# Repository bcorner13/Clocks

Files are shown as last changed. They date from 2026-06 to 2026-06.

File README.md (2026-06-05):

# Clocks

Parametric wall-clock product line for FreeCAD 1.1 → FDM print. One shared mounting bracket
and a parametric face template with interchangeable face SKUs.

## Product line

| File | Role | Orientation | Notes |
|---|---|---|---|
| `ClockFace-blank.FCStd` | Parametric **template** for face SKUs (disc + movement pocket) | XZ-vertical → reorient pending | base for lines/number |
| `ClockFace-lines.FCStd` | SKU: line/tick face markings (Hours ×12, HalfHour ×12) | XZ-vertical → reorient pending | |
| `ClockFace-number.FCStd` | SKU: numeric face markings | **XY-flat (target)** | clean datum-attached model |
| `ClockBracket.FCStd` | Shared wall mounting bracket | independent | |
| `Params.FCStd` | Central VarSet — all parametric variables | n/a | `<<Params>>#VarSet.Var` |

## Status (2026-06-04)

Retroactively bootstrapped to `PROJECT_BOOTSTRAP.md`. Bootstrap, central-Params migration, and
the blank/lines XY-flat reorient are **done**; the full project passes `audit_parametric.py`.
Architecture decisions and accepted tradeoffs are tracked in [`WARNINGS.md`](WARNINGS.md).

**Architecture:** central `Params.FCStd` drives all dimensions; geometry XLinks were evaluated
and **declined** (YAGNI — Params already syncs dimensions). **Remaining:** first PLA test print
(print profile TBD).

## Layout

- FCStd sources at root; `3mf/` + `stl/` tracked deliverables; `gcode/` regenerable (gitignored).
- `macros/` reviewable FreeCAD macros; `scripts/audit_parametric.py` parametric audit.
- `docs/superpowers/specs/` design specs; `docs/superpowers/plans/` execution plan.

## Standards

Inherits the workspace standards (`CAD_STANDARDS.md`, `PROJECT_BOOTSTRAP.md`,
`MCP_TOOLS_REFERENCE.md`, `tools.md`) and the global parametric rules in `~/.claude/CLAUDE.md`.
Run `python3 scripts/audit_parametric.py` before committing any geometry milestone.

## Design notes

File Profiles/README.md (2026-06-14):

# Profiles — canonical clock-face base

Home for **`ClockFace.base.3mf`** — the single source of truth that bakes print settings into
every exported face.

## What `ClockFace.base.3mf` is

A Creality Print **project** `.3mf`, saved from a *verified* 3-part face plate (the Roman plate),
containing all three things FreeCAD can't write:

- **print profile** — `Metadata/project_settings.config` (this plate: 0.12 layer, 2 walls, 15%
  infill, Textured PEI, your temps);
- **3-part structure** — dial / bezel / text as parts;
- **slot assignment + assemble** — which part prints in which CFS slot, grouped so they move together.

Because every face variant shares this structure and profile, **one base serves them all.**

## How to create / update it

In Creality Print, open a known-good 3-part plate (Roman is the reference), with the slots
assigned the way you want as defaults, then **File → Save Project As → `Profiles/ClockFace.base.3mf`**.

Re-tuned the profile (e.g. dialed in the holo plate)? Re-save the base from Creality and **every
face inherits the new settings** on its next export. Single source of truth.

This file is **tracked** in git (it's a valuable asset), unlike scratch exports in `archive/`.

## How the export uses it (the injector)

`macros/export_face_multicolor_3mf.FCMacro` will gain a `BASE_3MF` pointer to this file. On export
it:
1. copies this base,
2. swaps in the active face's three meshes (base / bezel / text, matched by order),
3. keeps `project_settings.config`, `model_settings.config`, slots, and assemble untouched,
4. writes `3mf/<DocLabel>.3mf` — opens in Creality already settings-loaded, 3-part, slot-colored.

Same trick as the 2cv001 macro ("reference a base 3MF, swap geometry, keep the rest"), just
multi-part aware. See `docs/superpowers/specs/2026-06-05-print-workflow-and-multicolor-design.md` §8.

## Status

⏳ **Base not saved yet.** The injector is built/verified against the real base once
`ClockFace.base.3mf` exists here — its exact internal structure (one-object-with-parts vs
separate-objects-with-assemble) decides the swap details, so it's developed against the actual file,
not blind.

## Also a candidate home for

Exported slicer **process profiles** (e.g. the days-tuned holo-plate profile) — back them up here or
at a workspace-level `Commercial License/Profiles/` if shared across projects. (Parked.)

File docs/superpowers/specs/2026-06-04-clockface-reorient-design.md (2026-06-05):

# ClockFace Reorient Design Spec (blank & lines → XY-flat)

**Date:** 2026-06-04
**Project:** Clocks
**Status:** Approved by Bradley — pending implementation plan
**Type:** Geometry reorient (re-attach in place; no redraw unless fallback triggers)
**Priority:** Runs after bootstrap scaffolding + Params migration (see `2026-06-04-clocks-bootstrap-design.md`)

---

## Why this exists

This spec defines the XZ→XY reorient of `ClockFace-blank` and `ClockFace-lines` to match
`ClockFace-number`. Per Bradley's final call, it honors the bootstrap spec's documented
order — **Params migration → reorient → XLink wiring** — so the reorient operates on
sketches whose dimensional constraints are already bound to `<<Params>>` expressions. The
bootstrap spec (`2026-06-04-clocks-bootstrap-design.md`) governs the scaffolding + the
Params migration that precede this reorient.

## Correction to the bootstrap spec's plane facts

Inspection of the live FCStds proved the bootstrap spec mislabeled the planes. The
corrected, verified reality:

| File | Disc lies in | Thickness along | Base `Sketch` attaches to | Markings/pocket attach to |
|---|---|---|---|---|
| `ClockFace-number` (**target**) | **XY** (flat on bed) | **Z** (0→3) | `XZ_Plane` (datum) | `XY_Plane` **datum** ✅ |
| `ClockFace-blank` (current) | XZ (standing up) | **Y** (−3→0) | `YZ_Plane` (datum) | `Revolution.Face5` **feature face** ⚠️ |
| `ClockFace-lines` (current) | XZ (standing up) | **Y** (−3→0) | `YZ_Plane` (datum) | `Pocket.Face5` **feature face** ⚠️ |

So the inconsistency is **two** problems, not one:
1. **Orientation** — blank/lines stand vertical (thickness in Y); number lies flat (thickness in Z).
2. **Coupling/DAG debt** — blank/lines anchor downstream sketches to *feature faces*; number anchors to the `XY_Plane` *datum*. The global rules flag feature-face attachment as a DAG-cycle red flag.

`ClockFace-number` already embodies the clean target on both counts. The goal of this work
is to make blank and lines match it.

## Verified current recipes

**number (target):** base `Sketch` on `XZ_Plane`; `Revolution` axis ≈ (0,0,−1) → spins
profile around **Z**, disc flat in XY (Z 0→3); `Sketch001` (movement pocket) on `XY_Plane`
datum.

**blank (current):** base `Sketch` on `YZ_Plane`; `Revolution` axis = (0,1,0) → spins
around **Y**, disc in XZ (Y −3→0); `Sketch001` on `Revolution.Face5`; `Pocket` UpToFirst.

**lines (current):** identical base to blank, plus `Sketch002` "Hours" (4 line segments,
11 constraints) → `Pad` 1.0mm → `PolarPattern` ×12 around sketch N_Axis; and `Sketch004`
"HalfHour" (5 line segments, 14 constraints) → `Pad001` 0.5mm → `PolarPattern001` ×12.
Both marking sketches anchor to `Pocket.Face5` (feature face ⚠️).

## Approach — re-attach in place (decided)

Chosen over (a) Body.Placement rotation and (b) re-attach base sketch only. Rationale:
matches number's clean datum structure, fixes orientation AND DAG debt in one pass, and
preserves all constrained geometry. The reorient is **independent of the constraint
values** — re-attaching a sketch to a different datum does not touch its dimensional
constraints. Since Params migration runs first, those constraints are already
`<<Params>>#VarSet.Var` expressions when the reorient happens, and re-attachment preserves
them unchanged.

### ClockFace-blank (macro `macros/reorient_blank_to_xy.FCMacro`)
1. Snapshot to `ClockFace-blank.Session-20260604.FCStd` first (session-hygiene rule).
2. Re-attach base `Sketch`: `YZ_Plane` → `XZ_Plane`, matching number's MapMode/placement,
   so the revolve axis becomes Z and the disc lands flat in XY.
3. Retarget `Sketch001` (movement pocket): `Revolution.Face5` → `XY_Plane` datum, as number does.
4. Recompute. Verify disc flat in XY (bbox dz ≈ 3, disc in XY), pocket on the correct face.
   Flip `Revolution.Reversed` / `Pocket.Reversed` if the solid builds on the wrong side.
5. Screenshot for Bradley's review. **No save until approved.**

### ClockFace-lines (macro `macros/reorient_lines_to_xy.FCMacro`)
Steps 1–3 as blank, then:
6. Retarget `Sketch002` (Hours) and `Sketch004` (HalfHour): `Pocket.Face5` → `XY_Plane`
   datum (or a thin offset datum at the face surface), preserving line geometry + polar patterns.
7. Recompute full tree (Pocket → Pad → PolarPattern → Pad001 → PolarPattern001).
8. Verify markings sit on the visible face, centered and radial; screenshot for review.

### Fallback for markings (decided: recreate)
Marking sketches were authored in the `Pocket.Face5` local frame; their 2D coordinates may
not land correctly on the `XY_Plane` datum. If a re-attached marking sketch mis-places, the
fallback is to **recreate that sketch** on the datum to match the original geometry (same
segment lengths, radial positions, constraints), verified visually. Bradley chose recreate
over pause-and-show. Because Params migration runs first, a recreated sketch binds its
dimensional constraints **directly to `<<Params>>` expressions** — no literal-coordinate
debt is introduced (this supersedes the earlier R4 concern).

## Constraints / rules honored

- All edits via reviewable macros under `macros/`; no direct FCStd XML surgery.
- Sketches end up on **datum/principal planes only** — never feature faces (global rule #3).
- **No raw coordinate edits** to fix geometry; reorientation is via attachment + revolve axis,
  not by editing StartX/EndY etc. (global rules #1/#2). Recreate-fallback redraws against the
  same dimensional intent, to be Params-migrated later.
- Dimensional constraints are **left as-is** (still literals) — Params migration is a separate,
  later pass and is explicitly out of scope here.

## Out of scope (handled elsewhere, not in this spec)

- Params migration (literals → `<<Params>>#VarSet.Var`) — runs **before** this reorient, per
  the bootstrap spec. Not redefined here.
- XLink wiring (lines/number → blank) — runs after this reorient.
- Any change to `ClockBracket.FCStd`.
- Re-export of STL/3MF — **decided: leave for later** (reorient FCStd source only this session;
  regenerate exports after Bradley reviews the reoriented models).

## Sequence (honors bootstrap spec ordering)

1. Retroactive bootstrap scaffolding per `2026-06-04-clocks-bootstrap-design.md` (creates the
   empty `Params.FCStd`, CLAUDE.md, audit, git, etc.).
2. Params migration: populate `Params.FCStd` and rewrite literal dimensional constraints in
   blank/lines/number/bracket as `<<Params>>#VarSet.Var` expressions.
3. Reorient blank → verify/screenshot → Bradley approves → save.
4. Reorient lines → verify/screenshot → Bradley approves → save.
5. (Later) XLink wiring.

The stub `macros/reorient_blank_lines_to_xy.FCMacro` named in the bootstrap spec is superseded
by the two real macros above (`reorient_blank_to_xy.FCMacro`, `reorient_lines_to_xy.FCMacro`);
note this in the bootstrap scaffolding.

## Acceptance criteria

- [ ] `ClockFace-blank`: base `Sketch` on `XZ_Plane`; `Sketch001` on `XY_Plane` datum;
      bbox thickness along Z (dz ≈ 3), disc in XY; recompute clean (no DAG errors).
- [ ] `ClockFace-lines`: same as blank, plus `Sketch002`/`Sketch004` on a datum (not
      `Pocket.Face5`); polar patterns intact (×12 each); markings centered/radial on the face.
- [ ] No sketch in either file attaches to a feature face after the reorient.
- [ ] Dimensional constraints remain bound to `<<Params>>` expressions through the reorient
      (re-attached sketches keep their expressions; any recreated sketch binds to Params).
- [ ] A pre-edit `*.Session-20260604.FCStd` snapshot exists for each file.
- [ ] Both files saved only after Bradley approves the screenshots.
- [ ] STL/3MF not regenerated (deferred).

## Risks

- **R1 — Marking sketches mis-place on re-attach.** Mitigated by the recreate fallback.
- **R2 — Revolve builds on the wrong side after axis change.** Mitigated by checking bbox
  Z-range and flipping `Reversed`.
- **R3 — `FaceN` topological-naming breakage cascades during re-attach.** Expected; the whole
  point is to move *off* those faces onto datums. Recompute after each step and verify before
  proceeding to the next sketch.
- **R4 — Recreate-fallback geometry drift.** Because Params migration runs first, a recreated
  sketch binds directly to `<<Params>>` expressions (no literal debt). Residual risk is only
  visual placement drift, mitigated by screenshot verification before save.

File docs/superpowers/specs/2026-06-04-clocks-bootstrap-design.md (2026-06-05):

# Clocks Project — Bootstrap Design Spec

**Date:** 2026-06-04
**Project:** Clocks
**Status:** Approved — pending implementation plan
**Type:** Retroactive project bootstrap (scaffolding-only; no geometry edits)

---

## Overview

The `Clocks/` folder under `~/Documents/3dPrinting/Commercial License/` already contains five in-progress FCStd files and exported `.stl`/`.3mf` outputs but has none of the structure required by `PROJECT_BOOTSTRAP.md`. This spec defines a retroactive in-place bootstrap that adds the missing scaffolding around the existing CAD files without touching their geometry. Known parametric debt and a known sketch-plane inconsistency are documented for follow-on work, not fixed here.

## Goals

1. Bring `Clocks/` into compliance with `PROJECT_BOOTSTRAP.md` structure.
2. Preserve all existing FCStd files and their `.FCBak` backups; preserve `3mf/` and `stl/` outputs.
3. Run the parametric audit and capture every violation in `WARNINGS.md` as a future-work checklist.
4. Document the known XZ→XY sketch-plane inconsistency between SKUs and stage (but do not run) a reorient macro.
5. Remove only one confirmed duplicate: `ClockFace.FCStd` (duplicate of `ClockFace-blank.FCStd`).
6. Document that no XLinks exist yet between any FCStds — the "live parametric parent" topology is **intended future state**, not current reality.

## Non-goals

- Migrating literal numeric values from existing sketches into `Params.FCStd`.
- Reorienting `ClockFace-blank` or `ClockFace-lines` from XZ_Plane to XY_Plane.
- Wiring up XLinks from `ClockFace-lines` / `ClockFace-number` back to `ClockFace-blank`. (Confirmed by Bradley: no XLinks exist between any FCStds today. The topology in §"Product topology" is the *intended* end state, deferred to follow-on work.)
- Any change to `ClockBracket.FCStd`'s mounting geometry.
- Re-slicing or re-exporting any existing `.stl` / `.3mf`.

## Product topology (intended)

| File | Role | Depends on | Plane at bootstrap |
|---|---|---|---|
| `Params.FCStd` | VarSet — all parametric variables | — | n/a |
| `ClockFace-blank.FCStd` | Parametric **template** for face SKUs; defines disc, bezel, movement boss, mounting interface | `Params.FCStd` | **XZ_Plane** (inconsistent — reorient pending) |
| `ClockFace-lines.FCStd` | SKU: line-style face markings, XLinks to `ClockFace-blank` for base geometry | `Params.FCStd`, `ClockFace-blank.FCStd` | **XZ_Plane** (inconsistent — reorient pending) |
| `ClockFace-number.FCStd` | SKU: numeric face markings, XLinks to `ClockFace-blank` for base geometry | `Params.FCStd`, `ClockFace-blank.FCStd` | **XY_Plane** (target orientation) |
| `ClockBracket.FCStd` | Shared mounting bracket for all face SKUs | `Params.FCStd` | n/a (independent) |

The XLink relationships above describe the **intended** architecture. **No XLinks exist in any current FCStd** (confirmed by Bradley). Every FCStd is currently independent: edits to `ClockFace-blank` do not propagate, and `ClockFace-lines` / `ClockFace-number` carry their own copies of the face base geometry. Wiring up the XLinks is follow-on work.

## intent.md (content to be written verbatim)

```
Goal:
Parametric wall clock product line — one shared mounting bracket and a
parametric face template (ClockFace-blank), with interchangeable face
SKUs (ClockFace-lines, ClockFace-number) XLinked from the template so
common dimensions stay synchronized across the product line.

Constraints:
* Must follow CAD_STANDARDS.md
* Target price $36–$45 per CAD_STANDARDS.md
* K2 Plus build plate (350×350mm); designs must fit
* Standard quartz movement (~6mm shaft) — bracket and face must accommodate
* PLA for test prints; ASA or other engineering plastic for production
* Printable without supports where possible
```

## plan.md (content outline)

**PARAMETERS** — initial set; Bradley refines in follow-on migration.

```
FaceDiameter              App::PropertyLength  — clock face overall OD
FaceThickness             App::PropertyLength
BezelWidth                App::PropertyLength
MovementBossDiameter      App::PropertyLength
MovementShaftHoleDiameter App::PropertyLength  — derived: shaft Ø + MovementShaftClearance
MovementShaftClearance    App::PropertyLength  — slip fit, face-to-shaft
MountingScrewHoleDiameter App::PropertyLength  — derived: screw Ø + MountingScrewClearance
MountingScrewClearance    App::PropertyLength  — bracket-to-wall fastener fit
BracketWidth              App::PropertyLength
BracketHeight             App::PropertyLength
BracketThickness          App::PropertyLength
WallThickness             App::PropertyLength
```

**FEATURE TREE** — documents XLink topology, not feature-by-feature modeling steps (which require post-Params-migration design).

**CONSTRAINT STRATEGY**:
- Every dimensional sketch constraint binds via `setExpression` to `<<Params>>#VarSet.<Var>`.
- Sketches attach to `PartDesign::Plane` datums only — never to feature faces (DAG-cycle risk).
- SKU XLinks reference datum geometry of the parent (`ClockFace-blank`), never feature faces.

**VALIDATION**:
- `python3 scripts/audit_parametric.py` reports clean before any commit.
- Each face SKU prints in PLA before being declared production-ready.

**Planned reorient (XZ → XY)**: described in §"Pending follow-on work" below.

## CLAUDE.md fills (key sections)

- **Headline (project-specific parametric risk):** "Every FCStd in this project is currently independent — no XLinks, no shared Params. Two consequences: (a) common dimensions are duplicated across blank/lines/number/bracket, and changing one will silently desync the others; (b) the immediate parametric debt is literal numbers in sketches. Migrate to Params *before* wiring up XLinks — wiring up first will only propagate the debt."
- **Hard rule #1:** Cite "No prior incident in this project; files predate parametric-rigor bootstrap. Audit-flagged literals (see WARNINGS.md) will be migrated to Params via macros, not coordinate edits."
- **Hard rule #2:** Cite "No prior coordinate-edit incident in this project; rule applies preventively."
- **Hard rule #3:** Cite "ClockFace-lines/number do not yet XLink to ClockFace-blank, but they will. Before XLinks are wired, any sketch in blank that attaches to a feature face (not a datum) must be retargeted to a datum — otherwise the first SKU recompute after wiring will produce a DAG cycle. The audit will flag candidates."
- **Hard rule #4 (clearance Params):** Lists `MovementShaftClearance` and `MountingScrewClearance` as the initial decoupled clearances; explicitly states do **not** overload `WallThickness` to express either.
- **§Project-specific quirks** includes:
  > `ClockFace-blank` and `ClockFace-lines` sketches attach to XZ_Plane; `ClockFace-number` attaches to XY_Plane. Inconsistent. A stub reorient macro at `macros/reorient_blank_lines_to_xy.FCMacro` is staged but **not executed**. Do not derive new face SKUs from `ClockFace-blank` until the reorient runs. See `WARNINGS.md` for full context.
- **Print profile**: "**No successful test print yet — profile TBD.**" (table omitted)
- **Memory files**: "No project-scoped memories yet — this is a fresh project."

## File operations

### Create (copied verbatim from workspace root, no edits)
- `Clocks/CAD_STANDARDS.md`
- `Clocks/MCP_TOOLS_REFERENCE.md`
- `Clocks/tools.md`

### Create (filled with project-specific content)
- `Clocks/CLAUDE.md` — from `CLAUDE_TEMPLATE.md`, every `[FILL: …]` replaced
- `Clocks/intent.md` — content per §intent.md above
- `Clocks/plan.md` — content per §plan.md outline above
- `Clocks/README.md` — overview, SKU table, links to spec
- `Clocks/.gitignore` — `*.FCBak`, `__pycache__/`, `gcode/`, `.DS_Store`
- `Clocks/WARNINGS.md` — captures audit findings + plane-inconsistency note

### Create (copied from canonical reference: `Daytona Coupe/Spade Connector Distribution Block - 4854104/`)
- `Clocks/scripts/audit_parametric.py`

### Create (empty placeholders)
- `Clocks/gcode/.gitkeep`
- `Clocks/images/.gitkeep`
- `Clocks/macros/` directory

### Create (stub macro — not executed)
- `Clocks/macros/reorient_blank_lines_to_xy.FCMacro` — header comment describing intent + a guarded `raise NotImplementedError("Review and uncomment plan body before executing.")`

### Create via FreeCAD MCP (GUI required)
- `Clocks/Params.FCStd` — empty App::VarSet document. Bootstrap macro creates the document, adds an empty `VarSet` object, saves. No properties added yet.

### Delete (after user confirmation in the implementation phase)
- `Clocks/ClockFace.FCStd` — confirmed duplicate of `ClockFace-blank.FCStd`. Bradley confirmed during brainstorm.

### Untouched
- `ClockBracket.FCStd`, `ClockFace-blank.FCStd`, `ClockFace-lines.FCStd`, `ClockFace-number.FCStd`
- All `*.FCBak` files (gitignored, not deleted)
- `3mf/`, `stl/` directories and all contents

### Git + remote (must be part of the bootstrap, not deferred)

The `Clocks/` folder is not a git repo today. Per Bradley's standard, project setup includes remote-repo creation:

1. `git init` inside `Clocks/`.
2. Stage all scaffolding (created files above) + existing FCStds + `stl/` + `3mf/`. **Do not stage** `*.FCBak` (gitignored).
3. First commit with a message summarizing the retroactive bootstrap.
4. Create a **public** GitHub remote (default per Bradley's preference — paid private hosting is avoided).
5. `git push -u origin main`.
6. The spec file at `docs/superpowers/specs/2026-06-04-clocks-bootstrap-design.md` lands in the initial commit alongside everything else.

## Audit + WARNINGS.md plan

After scaffolding is in place but before the bootstrap is declared complete:

1. Run `python3 scripts/audit_parametric.py` against the four kept FCStds.
2. Capture results in `Clocks/WARNINGS.md` with one section per file. For each file, list:
   - Unbound dimensional constraints (literal-numeric debt)
   - Sketches attached to feature faces (DAG risk)
   - Sketches with zero constraints
3. Add a top-level `WARNINGS.md` section titled **"Sketch-plane inconsistency (XZ vs XY)"** describing the issue and pointing to `macros/reorient_blank_lines_to_xy.FCMacro`.
4. Add a top-level `WARNINGS.md` section titled **"No XLinks today — intended topology is aspirational"** stating that every FCStd is currently independent, common dimensions are duplicated, and wiring up XLinks is follow-on work that must happen *after* Params migration (so XLinks propagate Params expressions, not literal-number debt).
5. Update `CLAUDE.md §Files in this project` to mark each FCStd ⚠️ with a count of violations and a one-line summary; cross-reference `WARNINGS.md`.

The bootstrap does **not** fix any audit violation. It only records them.

## Pending follow-on work (out of scope for this bootstrap)

These are deliberately deferred. They are listed so the implementation plan and `WARNINGS.md` can cross-reference them.

1. **Params migration** — populate `Params.FCStd` with the parameters listed in §plan.md and rewrite every literal-numeric sketch constraint in the four FCStds as `<<Params>>#VarSet.<Var>` expressions.
2. **Sketch-plane reorient** — `ClockFace-blank` and `ClockFace-lines` from XZ_Plane to XY_Plane via `macros/reorient_blank_lines_to_xy.FCMacro`, using new `PartDesign::Plane` datums and re-attaching existing sketches. Must run **after** Params migration, so re-anchored sketches use Params expressions, not literals.
3. **XLink wiring** — establish XLinks from `ClockFace-lines` / `ClockFace-number` to `ClockFace-blank` datum geometry. Must run **after** Params migration so the XLinks propagate Params-driven dimensions, not duplicated literals. Order: Params migration → reorient → XLink wiring.
4. **First test print** — produce the print profile table in CLAUDE.md from a real PLA print of `ClockFace-lines` + `ClockBracket`.

## Acceptance criteria

The bootstrap implementation is complete when **all** of the following hold:

- [ ] Every file listed under §"File operations → Create" exists in `Clocks/`.
- [ ] `Clocks/CLAUDE.md` contains zero `[FILL: …]` markers.
- [ ] `Clocks/Params.FCStd` opens in FreeCAD and contains exactly one `App::VarSet` object with no properties.
- [ ] `python3 Clocks/scripts/audit_parametric.py` runs (clean output not required at this stage; violations are expected and documented).
- [ ] `Clocks/WARNINGS.md` lists every audit violation and the plane-inconsistency note.
- [ ] `Clocks/ClockFace.FCStd` no longer exists.
- [ ] `Clocks/macros/reorient_blank_lines_to_xy.FCMacro` exists with header + `NotImplementedError` guard.
- [ ] Git status shows the scaffolding additions; no existing FCStd appears modified.
- [ ] `Clocks/` matches the directory layout mandated by `PROJECT_BOOTSTRAP.md`.
- [ ] `Clocks/` is a git repository with a public GitHub remote and an initial commit containing the scaffolding.

## Risks

- **R1 — Bootstrap reverses a wrong assumption.** Bradley initially indicated "live parametric parent (XLink)"; later confirmed no XLinks exist yet. The spec uses the corrected reality. If any FCStd is found to contain a stray XLink during the audit, treat it as a finding (record in WARNINGS.md) and re-confirm with Bradley before continuing.
- **R2 — `ClockFace.FCStd` is not actually a duplicate.** Bradley confirmed during brainstorm, but the implementation plan should `unzip -t` it and diff against `ClockFace-blank.FCStd` before deletion, just in case. Hold the file aside as a `.FCBak`-named archive if any byte differs in non-trivial ways.
- **R3 — Audit script from Spade has assumptions specific to that project.** If it errors when run against Clocks, fix it in `Clocks/scripts/audit_parametric.py` only — never modify the canonical copy.

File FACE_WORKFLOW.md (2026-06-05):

# New Clock Face — Workflow (e.g. Roman numerals, fun fonts)

Repeatable recipe to make a new face variant and get a no-painting, 3-color print plate
(dial / bezel / text). Macros live in `macros/` and are symlinked into FreeCAD's Macro menu.

## Steps

1. **Duplicate the template (FreeCAD).**
   Open `ClockFace-number.FCStd`, then **File → Save As → `ClockFace-<variant>.FCStd`**
   (e.g. `ClockFace-roman`). Use Save-As, *never* rename/`mv` the file — that breaks the Params
   cross-document link. Keep `Params.FCStd` open.

2. **Swap the numbers.**
   Delete the existing `FcClock001` group (the 12 numeral `ShapeString` + `Extrusion` objects).
   Run the **FCCircularText** macro with your new font / Roman numerals / characters. Place the
   text ring so it sits on the dial (inside radius ≈ 58.5 = `FaceDiameter/2 − BezelWidth`).
   Extrusion height doesn't matter — the next step re-seats it.

3. **Seat the text proud of the dial.**
   With the new face active, run **`seat_circular_text_proud`** (Macro menu). It lifts every text
   glyph onto the dial face and makes it stand proud by `NumeralReliefHeight` (1.5 mm),
   Params-bound, XY/rotation preserved. Eyeball it, then **save** the FCStd.

4. **Export the multi-color 3MF.**
   With the face active, run **`export_face_multicolor_3mf`** (Macro menu). It writes
   `3mf/ClockFace-<variant>.3mf` as **3 objects**: dial + bezel ring + text. (Bezel split radius
   is auto-read from Params. Set `SPLIT_BEZEL = False` at the top of the macro for a 2-object
   disc+text export instead.)
   *Optional STL for publishing:* export the Body + text fused if you want a single-color STL.

5. **Slice (Creality Print).**
   Open `3mf/ClockFace-<variant>.3mf`. On the **"Multi-part object detected"** prompt → **Yes**
   (loads as one object with parts → they move together AND take per-part filament).
   Assign 3 slots — dial / bezel / text — then **Slice**. No painting.

## Notes
- Steps 3–4 are the two project macros; FCCircularText is a third-party macro you already use.
- The bezel becomes its own color for free because step 4 splits the disc at the bezel radius —
  no slicer paint-by-layer needed.
- Everything stays Params-driven, so changing `FaceDiameter` / `BezelWidth` / `FacePlateThickness`
  / `NumeralReliefHeight` in `Params.FCStd` updates all faces.
- Run `python3 scripts/audit_parametric.py` before committing a face (should stay clean).

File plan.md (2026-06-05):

# Clocks — Plan

Generated for the retroactive bootstrap (2026-06-04). Geometry pre-exists; this plan
documents the parametric target, not a from-scratch modeling order. Authoritative specs:
`docs/superpowers/specs/2026-06-04-clocks-bootstrap-design.md` and
`docs/superpowers/specs/2026-06-04-clockface-reorient-design.md`. Execution plan:
`docs/superpowers/plans/2026-06-04-clocks-bootstrap-params-reorient.md`.

## PARAMETERS

Central VarSet lives in `Params.FCStd` (`VarSet`). Cross-document references use
`<<Params>>#VarSet.VarName`. Initial set (App::PropertyLength unless noted); refined during
the Params-migration pass to cover every literal found by `scripts/audit_parametric.py`.

| Name | Type | Meaning |
|---|---|---|
| FaceDiameter | Length | Clock face overall OD |
| FaceThickness | Length | Face disc thickness |
| BezelWidth | Length | Outer bezel ring width |
| MovementBossDiameter | Length | Boss around the movement bore |
| MovementShaftClearance | Length | Slip fit, face-to-shaft (decoupled clearance) |
| MovementShaftHoleDiameter | Length | Derived: shaft Ø + MovementShaftClearance |
| MountingScrewClearance | Length | Bracket-to-wall fastener fit (decoupled clearance) |
| MountingScrewHoleDiameter | Length | Derived: screw Ø + MountingScrewClearance |
| WallThickness | Length | General wall thickness |
| BracketWidth / BracketHeight / BracketThickness | Length | Mounting bracket envelope |
| HourMarkLength / HourMarkWidth / HourMarkPadHeight | Length | Hour tick geometry (pad 1.0mm) |
| HalfHourMarkLength / HalfHourMarkWidth / HalfHourMarkPadHeight | Length | Half-hour tick geometry (pad 0.5mm) |
| MarkCount | Integer | Tick repetitions (12) |

Decoupled-clearance rule: `MovementShaftClearance` and `MountingScrewClearance` are distinct
concepts — never overload `WallThickness` to express either.

## FEATURE TREE (per file)

- **ClockBracket** — wall mounting bracket (independent of faces).
- **ClockFace-blank** — `Sketch` (revolve profile) → `Revolution` (disc) → `Sketch001`
  (movement pocket) → `Pocket`. Parametric template for the face SKUs.
- **ClockFace-lines** — blank base, plus `Sketch002`/`Pad`/`PolarPattern` (Hours ×12) and
  `Sketch004`/`Pad001`/`PolarPattern001` (HalfHour ×12).
- **ClockFace-number** — blank base, plus numeric face markings. **Already in the target
  XY-flat orientation with markings on the `XY_Plane` datum** — the structural model the
  others copy.

## ORIENTATION STATUS (corrected 2026-06-04)

| File | Disc plane | Thickness | Marking/pocket attach | State |
|---|---|---|---|---|
| ClockFace-number | XY (flat) | Z | XY_Plane datum ✅ | target |
| ClockFace-blank | XZ (vertical) | Y | Revolution.Face5 ⚠️ | reorient pending |
| ClockFace-lines | XZ (vertical) | Y | Pocket.Face5 ⚠️ | reorient pending |

Reorient (Phase 3 of the execution plan) re-attaches blank & lines to datum planes and lays
them flat to match number.

## CONSTRAINT STRATEGY

- Every dimensional sketch constraint binds via `setExpression` to `<<Params>>#VarSet.<Var>`.
- Sketches attach to `PartDesign::Plane` datums / principal planes only — never feature
  faces (DAG-cycle risk).
- SKU XLinks (future) reference datum geometry of the parent (`ClockFace-blank`), never faces.

## VALIDATION

- `python3 scripts/audit_parametric.py` reports clean (B-spline `Weight` constraints exempt,
  per project decision) before any commit that claims a parametric milestone.
- Each face SKU prints in PLA before being declared production-ready.

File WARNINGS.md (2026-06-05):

# WARNINGS — Clocks parametric debt & known issues

Captured during the retroactive bootstrap (2026-06-04).

## STATUS after Params migration + reorient (2026-06-04)

**Params migration complete.** Every literal dimensional constraint across the four FCStds is
bound to `<<Params>>#VarSet.<Var>` in the central `Params.FCStd` (21 params). Geometry verified
unchanged (bbox + volume identical pre/post); central Params proven to drive geometry
(FaceDiameter round-trip). The bracket's pre-existing **local** VarSet (`InsideDistance`) was
migrated into central Params and the dead local VarSet deleted.

**Reorient complete.** `ClockFace-blank` and `ClockFace-lines` are now **XY-flat, ridge up
(disc Z 0→3), matching `ClockFace-number`**. Base `Sketch`→`XZ_Plane`, `Sketch001`→`XY_Plane`;
lines' Hours/HalfHour markings moved off `Pocket.Face5` onto a new `DialFaceDatum` plane whose
Z-height is bound to `FacePlateThickness`. Re-attach was clean (pattern bbox + body volume
unchanged — no recreate fallback needed). The base flip used `Sketch.MapReversed=True` +
`Pocket.Reversed=True` to put the bezel ridge on +Z.

**✓ Corrected audit now passes on all five files.** No unbound dimensions, no feature-face DAG
risk. STL/3MF for blank & lines were re-exported in the new flat orientation
(watertight/manifold, 0.01 mm deflection). **Geometry XLink wiring was evaluated and declined
(2026-06-05)** — see the decision note below; nothing remains outstanding from the original
bootstrap/reorient plan.

> ⚠️ **Canonical `audit_parametric.py` bug (affects ALL projects).** The copied-from-Spade
> audit shipped a WRONG Sketcher constraint-type table — it labeled Tangent(5) as
> "ParallelDistance", Perpendicular(10) as "Angle", Block(17) as "Diameter", and missed real
> Radius(11)/Diameter(18). Result: it reported geometric constraints as unbound dimensions
> (the original "84 baseline" was heavily inflated with false positives). The **Clocks copy is
> fixed** (correct enum, verified 1:1 against the live Sketcher API, plus Type-aware feature
> dims and a 90°-angle exemption). The canonical copy and other projects' copies are still
> buggy — propagate the fix.

The historical baseline below is retained for reference; the per-file literal counts in it
were partly false positives from the audit bug. The DAG-risk findings in it are real.

---

## Historical baseline (pre-migration, pre-audit-fix — partly inflated)

Baseline audit (buggy script): **84 issues across 5 files** (the duplicate `ClockFace.FCStd`,
deleted during bootstrap, accounted for 8).

## Remediation order (per specs)

**Params migration → reorient (blank & lines) → ~~XLink wiring~~.** Params migration and the
reorient are done. **Geometry XLink wiring was evaluated and declined on 2026-06-05** (YAGNI —
see the decision note below). Reorient ran *after* Params so re-attached sketches carry
`<<Params>>` expressions, not literals.

## Per-file audit findings (baseline)

### ClockBracket.FCStd — 38 issues
- `Sketch`: 22 unbound dimensional constraints (DistanceX/Y, ParallelDistance, Distance).
- `Sketch001`: 9 unbound dimensional constraints.
- `Sketch002.Constraints[0]`: `Weight` — **B-spline weight, exempt** (see exemption note).
- Feature dims unbound: `Pad.Length/Length2`, `Pad001.Length/Length2`, `Pocket.Length/Length2`.
- No feature-face attachment (bracket is structurally clean on attachment).

### ClockFace-blank.FCStd — 8 issues
- `Sketch`: 4 unbound dimensional constraints (Constraints[13,14,15,16]).
- `Sketch001.Constraints[0]`: `Weight` — exempt.
- ⚠️ **DAG RISK**: `Sketch001` attached to feature face `Revolution.Face5` → retarget to datum (Phase 3).
- Feature dims unbound: `Pocket.Length/Length2`.

### ClockFace-lines.FCStd — 23 issues
- `Sketch`: 4 unbound dimensional constraints (same as blank base).
- `Sketch001.Constraints[0]`: `Weight` — exempt.
- ⚠️ **DAG RISK**: `Sketch001` → `Revolution.Face5`; `Sketch002` (Hours) → `Pocket.Face5`;
  `Sketch004` (HalfHour) → `Pocket.Face5`. All three retarget to datums (Phase 3).
- `Sketch002`: 3 unbound dims. `Sketch004`: 6 unbound dims (incl. 3 Radius).
- Feature dims unbound: `Pad.Length/Length2`, `Pad001.Length/Length2`, `Pocket.Length/Length2`.

### ClockFace-number.FCStd — 7 issues
- `Sketch`: 4 unbound dimensional constraints.
- `Sketch001.Constraints[0]`: `Weight` — exempt.
- Feature dims unbound: `Pocket.Length/Length2`.
- **No feature-face attachment** — already the clean structural target (markings on XY_Plane datum).

## Sketch-orientation inconsistency (vertical vs XY-flat)

`ClockFace-number` lies flat in XY (thickness along Z) with its movement/marking sketches on
the `XY_Plane` datum — the desired state. `ClockFace-blank` and `ClockFace-lines` stand
vertical (disc in XZ, thickness along Y) with downstream sketches anchored to **feature
faces**. The reorient (`macros/reorient_blank_to_xy.FCMacro`,
`macros/reorient_lines_to_xy.FCMacro`) lays them flat and re-attaches their sketches to datum
planes, matching number. These two real macros supersede the bootstrap spec's stub
`macros/reorient_blank_lines_to_xy.FCMacro`. Do not derive new face SKUs from `ClockFace-blank`
until the reorient runs.

## Decision (2026-06-05): central Params, no geometry XLinks

Originally the "live parametric parent (XLink)" topology was the intended end state. It was
evaluated after the Params migration and **declined (YAGNI)**:

- **Dimension sync is already solved** by the central `Params.FCStd` VarSet — all four FCStds
  reference `<<Params>>#VarSet.*`, so common dimensions stay synchronized with no XLinks.
- **What geometry-XLinking would add** is base-disc *topology* inheritance (a structural change
  to blank's profile propagating to lines/number). For a clock line where the disc is stable and
  only the markings vary, that benefit is marginal.
- **What it would cost** is rebuilding the two clean, audit-passing SKU files to consume blank's
  body via cross-document SubShapeBinders, plus topological-naming fragility (XLinks break on
  FCStd rename) and recompute-order coupling.

**Accepted consequence:** the base disc geometry is duplicated across the face SKUs, so a
*structural* (not dimensional) change to the base profile must be replicated by hand in each.
Revisit XLinking only if such structural changes become frequent.

## Audit exemption: B-spline `Weight` constraints

`Sketcher` `Weight` constraints (Type 18) on B-spline poles are control-point weights, not
user-facing dimensions. Per project decision they are **exempt** from the parametric-binding
requirement. The audit currently flags them; treat those specific lines as known-exempt.

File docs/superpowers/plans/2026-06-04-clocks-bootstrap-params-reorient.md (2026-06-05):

# Clocks: Bootstrap → Params Migration → Reorient — Implementation Plan

> **For agentic workers:** REQUIRED SUB-SKILL: Use superpowers:subagent-driven-development (recommended) or superpowers:executing-plans to implement this plan task-by-task. Steps use checkbox (`- [ ]`) syntax for tracking.

**Goal:** Bring `Clocks/` into `PROJECT_BOOTSTRAP.md` compliance, migrate every literal sketch dimension to a central `Params.FCStd` VarSet, then reorient `ClockFace-blank` and `ClockFace-lines` from vertical (disc in XZ, thickness Y) to flat (disc in XY, thickness Z) so they match `ClockFace-number`'s clean datum-attached structure.

**Architecture:** Three sequential phases. (1) Scaffolding is plain file creation copied from the workspace root + canonical Spade reference, plus `git init` and a public GitHub remote. (2) Params migration uses a single reusable binding helper macro driven by a per-sketch mapping table that an inspection task produces from the live FCStds. (3) Reorient re-attaches existing sketches from feature faces onto datum planes via two reviewable macros; mis-placed marking sketches are recreated bound to Params. Every FreeCAD edit is a reviewable, idempotent macro under `macros/`; nothing is saved until a screenshot is approved.

**Tech Stack:** FreeCAD 1.1.1 via the `freecad` MCP server (xmlrpc, GUI up), Python 3.13, `audit_parametric.py`, git + `gh` CLI.

**Source specs:**
- `docs/superpowers/specs/2026-06-04-clocks-bootstrap-design.md` (scaffolding)
- `docs/superpowers/specs/2026-06-04-clockface-reorient-design.md` (reorient)

**Global rules in force (from `~/.claude/CLAUDE.md`):** everything parametric; no raw coordinate edits; sketches on datum planes only; decoupled clearance Params; changes as macros; cross-doc expressions use `<<Params>>#VarSet.VarName`; never auto-save — snapshot to `*.Session-YYYYMMDD.FCStd` before risky edits.

---

## File Structure (created / modified)

**Created — scaffolding (Phase 1):**
- `Clocks/CLAUDE.md` — from root `CLAUDE_TEMPLATE.md`, all `[FILL: …]` replaced
- `Clocks/intent.md`, `Clocks/plan.md`, `Clocks/README.md`, `Clocks/WARNINGS.md`
- `Clocks/.gitignore`
- `Clocks/CAD_STANDARDS.md`, `Clocks/MCP_TOOLS_REFERENCE.md`, `Clocks/tools.md` (verbatim copies)
- `Clocks/scripts/audit_parametric.py` (copy from canonical Spade reference)
- `Clocks/gcode/.gitkeep`, `Clocks/images/.gitkeep`, `Clocks/macros/` (dir)
- `Clocks/Params.FCStd` (empty App::VarSet doc, via macro)

**Created — macros (Phases 2–3):**
- `Clocks/macros/bind_constraints_to_params.FCMacro` (reusable binding helper)
- `Clocks/macros/populate_params_varset.FCMacro` (creates the Param properties)
- `Clocks/macros/reorient_blank_to_xy.FCMacro`
- `Clocks/macros/reorient_lines_to_xy.FCMacro`

**Modified (Phase 2–3, via macros only, saved after approval):**
- `Clocks/ClockFace-blank.FCStd`, `Clocks/ClockFace-lines.FCStd`, `Clocks/ClockFace-number.FCStd`, `Clocks/ClockBracket.FCStd`

**Deleted (after byte-diff confirmation):**
- `Clocks/ClockFace.FCStd` (duplicate of `ClockFace-blank.FCStd`)

---

## Phase 0 — Pre-flight & snapshots

### Task 0.1: Snapshot every FCStd before any edit

**Files:** Create `Clocks/*.Session-20260604.FCStd` for each of the 5 FCStds.

- [ ] **Step 1: Copy each FCStd to a dated session snapshot**

```bash
cd "/Users/bradleycorner/Documents/3dPrinting/Commercial License/Clocks"
for f in ClockFace-blank ClockFace-lines ClockFace-number ClockBracket ClockFace; do
  cp -n "$f.FCStd" "$f.Session-20260604.FCStd"
done
ls *.Session-20260604.FCStd
```
Expected: 5 snapshot files listed.

- [ ] **Step 2: Verify each snapshot is a valid zip (FCStd is a zip)**

```bash
for f in *.Session-20260604.FCStd; do unzip -t "$f" >/dev/null && echo "OK  $f" || echo "BAD $f"; done
```
Expected: 5 lines all `OK`.

> Snapshots are gitignored (`*.Session-*.FCStd` matched by the `.gitignore` in Task 1.5). They are recovery points, not deliverables.

### Task 0.2: Confirm `ClockFace.FCStd` really duplicates `ClockFace-blank.FCStd`

**Files:** read-only inspection.

- [ ] **Step 1: Compare the two documents' object trees and geometry via MCP**

Run (MCP `execute_python`):
```python
import FreeCAD as App, filecmp
docs={d.Name:d for d in App.listDocuments().values()}
blank=docs["ClockFace_blank"]
# ClockFace.FCStd internal name is "ClockFace"? number is also "ClockFace" -> open dup under a temp
import os
p="/Users/bradleycorner/Documents/3dPrinting/Commercial License/Clocks/ClockFace.FCStd"
dup=App.openDocument(p)
def sig(doc):
    out=[]
    for o in doc.Objects:
        rec=(o.Name,o.TypeId)
        out.append(rec)
    bb=doc.getObject("Body").Shape.BoundBox if doc.getObject("Body") and doc.getObject("Body").Shape.Volume>0 else None
    return out,(round(bb.XLength,3),round(bb.YLength,3),round(bb.ZLength,3)) if bb else None
_result_={"dup":sig(dup),"blank":sig(blank)}
```
Expected: identical object lists and bbox dimensions ⇒ confirmed duplicate.

- [ ] **Step 2: Decision gate**

If signatures match: proceed; `ClockFace.FCStd` will be deleted in Task 1.7.
If they differ: STOP, report the difference to Bradley, keep the file, and remove its deletion from Task 1.7.

---

## Phase 1 — Retroactive bootstrap scaffolding

### Task 1.1: Copy verbatim standards files into the project

**Files:** Create `Clocks/CAD_STANDARDS.md`, `Clocks/MCP_TOOLS_REFERENCE.md`, `Clocks/tools.md`.

- [ ] **Step 1: Copy the three standards docs from the workspace root**

```bash
cd "/Users/bradleycorner/Documents/3dPrinting/Commercial License"
for f in CAD_STANDARDS.md MCP_TOOLS_REFERENCE.md tools.md; do cp "$f" "Clocks/$f"; done
ls -la Clocks/CAD_STANDARDS.md Clocks/MCP_TOOLS_REFERENCE.md Clocks/tools.md
```
Expected: 3 files present. These are read-only references — never edited in place.

### Task 1.2: Copy the audit script from the canonical reference

**Files:** Create `Clocks/scripts/audit_parametric.py`.

- [ ] **Step 1: Copy from the Spade Connector canonical project**

```bash
cd "/Users/bradleycorner/Documents/3dPrinting/Commercial License"
mkdir -p Clocks/scripts
cp "Daytona Coupe/Spade Connector Distribution Block - 4854104/scripts/audit_parametric.py" Clocks/scripts/audit_parametric.py
ls -la Clocks/scripts/audit_parametric.py
```
Expected: file present.

- [ ] **Step 2: Run it against the Clocks FCStds to confirm it executes (violations expected)**

```bash
cd "/Users/bradleycorner/Documents/3dPrinting/Commercial License/Clocks"
python3 scripts/audit_parametric.py 2>&1 | tee /tmp/clocks_audit_baseline.txt | tail -40
```
Expected: it runs and prints findings. If it errors on a Clocks-specific assumption, fix it **only in the Clocks copy** (never the canonical) and re-run. Save the baseline output — Phase 1 records it in WARNINGS.md, Phase 2 must clear it.

### Task 1.3: Create the directory placeholders

**Files:** Create `Clocks/gcode/.gitkeep`, `Clocks/images/.gitkeep`, `Clocks/macros/` dir.

- [ ] **Step 1: Make the folders**

```bash
cd "/Users/bradleycorner/Documents/3dPrinting/Commercial License/Clocks"
mkdir -p gcode images macros
touch gcode/.gitkeep images/.gitkeep
ls -d 3mf stl gcode images macros scripts docs
```
Expected: all directories listed (3mf, stl already exist).

### Task 1.4: Write `intent.md`

**Files:** Create `Clocks/intent.md`.

- [ ] **Step 1: Write the file verbatim from the bootstrap spec §intent.md**

```
Goal:
Parametric wall clock product line — one shared mounting bracket and a
parametric face template (ClockFace-blank), with interchangeable face
SKUs (ClockFace-lines, ClockFace-number) XLinked from the template so
common dimensions stay synchronized across the product line.

Constraints:
* Must follow CAD_STANDARDS.md
* Target price $36–$45 per CAD_STANDARDS.md
* K2 Plus build plate (350×350mm); designs must fit
* Standard quartz movement (~6mm shaft) — bracket and face must accommodate
* PLA for test prints; ASA or other engineering plastic for production
* Printable without supports where possible
```

### Task 1.5: Write `plan.md`, `README.md`, `.gitignore`

**Files:** Create `Clocks/plan.md`, `Clocks/README.md`, `Clocks/.gitignore`.

- [ ] **Step 1: `plan.md`** — copy the PARAMETERS / FEATURE TREE / CONSTRAINT STRATEGY / VALIDATION content from the bootstrap spec §plan.md verbatim, with the corrected plane facts from the reorient spec (number = XY-flat target; blank/lines reorient to match).

- [ ] **Step 2: `README.md`** — project overview, the SKU table (blank template, lines SKU, number SKU, bracket), links to both specs and this plan, and the current orientation status.

- [ ] **Step 3: `.gitignore`**

```gitignore
*.FCBak
*.Session-*.FCStd
__pycache__/
gcode/
.DS_Store
```

### Task 1.6: Fill `CLAUDE.md` from the template

**Files:** Create `Clocks/CLAUDE.md` from `../CLAUDE_TEMPLATE.md`.

- [ ] **Step 1: Copy the template**

```bash
cd "/Users/bradleycorner/Documents/3dPrinting/Commercial License"
cp CLAUDE_TEMPLATE.md Clocks/CLAUDE.md
grep -c "FILL" Clocks/CLAUDE.md
```
Expected: a positive count of `[FILL: …]` markers to replace.

- [ ] **Step 2: Replace every `[FILL: …]` marker** using the bootstrap spec §"CLAUDE.md fills" content, plus the corrected facts: blank & lines currently vertical (reorient pending until Phase 3), number already XY-flat and the structural model to copy; feature-face attachments in blank/lines are the DAG debt to retarget; clearance Params `MovementShaftClearance` + `MountingScrewClearance` decoupled, never overload `WallThickness`. Preserve every "do not edit" invariant section verbatim.

- [ ] **Step 3: Verify no markers remain**

```bash
grep -n "FILL" Clocks/CLAUDE.md || echo "CLEAN: no FILL markers"
```
Expected: `CLEAN: no FILL markers`.

### Task 1.7: Delete the confirmed duplicate

**Files:** Delete `Clocks/ClockFace.FCStd` (only if Task 0.2 confirmed duplicate).

- [ ] **Step 1: Close it in FreeCAD, then remove the file**

Run (MCP `execute_python`): `App.closeDocument("ClockFace")` for the *duplicate* doc only — verify by `.FileName` first so you don't close `ClockFace-number` (which also has internal name `ClockFace`). Then:
```bash
cd "/Users/bradleycorner/Documents/3dPrinting/Commercial License/Clocks"
rm ClockFace.FCStd
ls ClockFace*.FCStd
```
Expected: `ClockFace.FCStd` gone; the `.Session-20260604.FCStd` snapshot of it remains as archive.

### Task 1.8: Create empty `Params.FCStd`

**Files:** Create `Clocks/Params.FCStd` via MCP.

- [ ] **Step 1: Create the VarSet-only document**

Run (MCP `execute_python`):
```python
import FreeCAD as App
doc=App.newDocument("Params")
vs=doc.addObject("App::VarSet","VarSet")
vs.Label="VarSet"
doc.recompute()
doc.saveAs("/Users/bradleycorner/Documents/3dPrinting/Commercial License/Clocks/Params.FCStd")
_result_=[o.Name for o in doc.Objects]
```
Expected: `["VarSet"]`. No properties yet — populated in Phase 2.

### Task 1.9: Initialize git + public remote, first commit

**Files:** `Clocks/.git`, GitHub remote.

- [ ] **Step 1: Init and stage scaffolding (not snapshots/FCBak)**

```bash
cd "/Users/bradleycorner/Documents/3dPrinting/Commercial License/Clocks"
git init
git add CLAUDE.md intent.md plan.md README.md WARNINGS.md .gitignore \
  CAD_STANDARDS.md MCP_TOOLS_REFERENCE.md tools.md \
  scripts/ macros/ docs/ gcode/.gitkeep images/.gitkeep \
  Params.FCStd ClockBracket.FCStd ClockFace-blank.FCStd ClockFace-lines.FCStd ClockFace-number.FCStd \
  3mf/ stl/
git status --short
```
Expected: staged scaffolding + FCStds + outputs; **no** `*.FCBak` or `*.Session-*` staged.

- [ ] **Step 2: Commit**

```bash
git commit -m "Retroactive bootstrap: scaffold Clocks project per PROJECT_BOOTSTRAP.md

Adds CLAUDE.md, intent/plan/README/WARNINGS, standards copies, audit script,
empty Params.FCStd, and directory layout around existing in-progress FCStds.
Geometry untouched. Co-Authored-By: Claude Opus 4.8 (1M context) <noreply@anthropic.com>"
```

- [ ] **Step 3: Create the public remote and push**

```bash
cd "/Users/bradleycorner/Documents/3dPrinting/Commercial License/Clocks"
gh repo create Clocks --public --source=. --remote=origin --push
git remote -v
```
Expected: `origin` set to the new public GitHub repo; `main` pushed. (Public per Bradley's default.)

### Task 1.10: Phase-1 checkpoint

- [ ] **Step 1: Verify bootstrap acceptance**

```bash
cd "/Users/bradleycorner/Documents/3dPrinting/Commercial License/Clocks"
for d in 3mf stl gcode images macros scripts docs; do [ -d "$d" ] && echo "dir OK $d"; done
for f in CLAUDE.md intent.md plan.md README.md WARNINGS.md .gitignore Params.FCStd \
  CAD_STANDARDS.md MCP_TOOLS_REFERENCE.md tools.md scripts/audit_parametric.py; do [ -e "$f" ] && echo "file OK $f" || echo "MISSING $f"; done
grep -q FILL CLAUDE.md && echo "FAIL: FILL remains" || echo "CLAUDE clean"
```
Expected: all `OK`, `CLAUDE clean`, no `MISSING`. **STOP and report to Bradley before Phase 2.**

---

## Phase 2 — Params migration

> Reusable approach: one binding helper consumes a per-sketch mapping `{constraintName: ParamName}`. The mapping is produced by an inspection task per FCStd, then reviewed, then applied. Derived Params (e.g. hole Ø = shaft Ø + clearance) are set as expressions inside the VarSet itself.

### Task 2.1: Inspect every dimensional constraint across the four FCStds

**Files:** read-only.

- [ ] **Step 1: Dump named + unnamed dimensional constraints per sketch**

Run (MCP `execute_python`) for each of `ClockFace_blank`, `ClockFace_lines`, `ClockFace`(=number), `ClockBracket`:
```python
import FreeCAD as App
doc=App.getDocument("ClockFace_blank")  # repeat per doc
rows=[]
for o in doc.Objects:
    if o.TypeId!="Sketcher::SketchObject": continue
    for i,c in enumerate(o.Constraints):
        if c.Type in ("Distance","DistanceX","DistanceY","Radius","Diameter","Angle"):
            rows.append((o.Name,i,c.Name or "(unnamed)",c.Type,round(float(c.Value),4)))
_result_=rows
```
Expected: a table of (sketch, index, name, type, value). **Output of this task is the raw material for the mapping in Task 2.2.**

### Task 2.2: Author the Param set + mapping table

**Files:** update `Clocks/plan.md` (Params section), create the mapping used by Task 2.4.

- [ ] **Step 1: Define the VarSet Params** — start from the bootstrap spec list and extend to cover every distinct dimension found in Task 2.1. Initial set (App::PropertyLength unless noted):

```
FaceDiameter, FaceThickness, BezelWidth,
MovementBossDiameter, MovementShaftClearance,
MovementShaftHoleDiameter   (= MovementBossDiameter or shaft Ø + MovementShaftClearance — set as VarSet expression),
MountingScrewClearance, MountingScrewHoleDiameter (derived expression),
WallThickness,
BracketWidth, BracketHeight, BracketThickness,
HourMarkLength, HourMarkWidth, HourMarkPadHeight (=1.0),
HalfHourMarkLength, HalfHourMarkWidth, HalfHourMarkPadHeight (=0.5),
MarkCount (App::PropertyInteger, =12)
```
Add/rename to match Task 2.1 reality — one Param per distinct concept (global rule: one knob, one concern). Name unnamed driving constraints in the sketch first (so binding targets a stable name, not an index).

- [ ] **Step 2: Write the mapping table** `{(doc, sketch, constraintName): ParamName}` into a comment block at the top of `bind_constraints_to_params.FCMacro` (Task 2.3) so the binding is reviewable and re-runnable.

### Task 2.3: Write the reusable binding helper macro

**Files:** Create `Clocks/macros/bind_constraints_to_params.FCMacro`.

- [ ] **Step 1: Write the idempotent helper**

```python
# bind_constraints_to_params.FCMacro
# Binds named sketch constraints to <<Params>>#VarSet.<Param> expressions.
# Idempotent: re-running re-asserts expressions; never appends.
import FreeCAD as App

PARAMS_DOC = "Params"  # internal name of Params.FCStd once open

# MAPPING: (docName, sketchName, constraintName) -> ParamName
MAPPING = {
    # filled from Task 2.2, e.g.:
    # ("ClockFace_blank","Sketch","FaceDia"): "FaceDiameter",
}

def ensure_param(vs, name, ptype="App::PropertyLength", group="Clock", doc="auto"):
    if name not in vs.PropertiesList:
        vs.addProperty(ptype, name, group, doc)

def run():
    if PARAMS_DOC not in [d.Name for d in App.listDocuments().values()]:
        App.openDocument("/Users/bradleycorner/Documents/3dPrinting/Commercial License/Clocks/Params.FCStd")
    vs = App.getDocument(PARAMS_DOC).getObject("VarSet")
    for (dn, sn, cn), pname in MAPPING.items():
        doc = App.getDocument(dn); sk = doc.getObject(sn)
        ensure_param(vs, pname)
        # bind constraint -> Param
        sk.setExpression(f"Constraints.{cn}", f"<<Params>>#VarSet.{pname}")
        doc.recompute()
    App.getDocument(PARAMS_DOC).recompute()
    print("bound", len(MAPPING), "constraints")

run()
```
> `setExpression("Constraints.<Name>", ...)` requires the constraint to be **named**. Task 2.2 Step 1 names any unnamed driving constraint first.

### Task 2.4: Populate the VarSet with real values, then bind

**Files:** Create `Clocks/macros/populate_params_varset.FCMacro`; modify `Params.FCStd` + the four FCStds (in memory; saved in Task 2.6).

- [ ] **Step 1: Write `populate_params_varset.FCMacro`** that `addProperty` each Param (idempotent skip if present), sets its value from Task 2.1's measured numbers, and sets derived Params via `vs.setExpression("MovementShaftHoleDiameter", "...")` etc.

- [ ] **Step 2: Run populate, then run the binding helper**

Run both macros via MCP `execute_python` (exec file contents) or the Macro UI. After each, `recompute` the affected docs.

- [ ] **Step 3: Verify no geometry moved**

For each of the four FCStds, compare `Body.Shape.BoundBox` (XLength/YLength/ZLength rounded to 3dp) before (Task 2.1 era) and after binding.
Expected: **identical bboxes** — binding replaces literals with equal-valued expressions, so geometry must not move. Any change ⇒ a wrong Param value; fix before continuing.

### Task 2.5: Run the audit — must be clean

- [ ] **Step 1: Re-run audit**

```bash
cd "/Users/bradleycorner/Documents/3dPrinting/Commercial License/Clocks"
python3 scripts/audit_parametric.py 2>&1 | tee /tmp/clocks_audit_postparams.txt | tail -40
```
Expected: zero unbound dimensional constraints across blank/lines/number/bracket. (Feature-face DAG warnings on blank/lines may remain — those are cleared in Phase 3.) If unbound dims remain, extend MAPPING and re-run Task 2.4.

### Task 2.6: Save + commit Params migration

- [ ] **Step 1: Save all modified docs (only after Step 2.4.3 bbox check passes)**

Run (MCP): `App.getDocument(name).save()` for Params + the four FCStds.

- [ ] **Step 2: Commit**

```bash
cd "/Users/bradleycorner/Documents/3dPrinting/Commercial License/Clocks"
git add Params.FCStd ClockFace-blank.FCStd ClockFace-lines.FCStd ClockFace-number.FCStd ClockBracket.FCStd macros/ plan.md WARNINGS.md
git commit -m "Params migration: central VarSet + bind literal constraints to <<Params>>

Co-Authored-By: Claude Opus 4.8 (1M context) <noreply@anthropic.com>"
```

- [ ] **Step 3: Phase-2 checkpoint — STOP and report to Bradley before Phase 3.**

---

## Phase 3 — Reorient blank & lines to XY-flat

> Per reorient spec. Re-attach existing (now Params-bound) sketches from feature faces onto datum planes, matching `ClockFace-number`. Recompute and screenshot after each step; recreate a marking sketch (bound to Params) only if re-attach mis-places it. **No save until Bradley approves the screenshot.**

### Task 3.1: Capture number's exact target attachment recipe

**Files:** read-only.

- [ ] **Step 1: Record number's base `Sketch` MapMode/AttachmentSupport/placement and `Sketch001` (XY_Plane) details** via MCP, so blank/lines are re-attached to the identical configuration.
Expected: a concrete target spec (base sketch → XZ_Plane with number's MapMode; pocket sketch → XY_Plane datum).

### Task 3.2: Write & run `reorient_blank_to_xy.FCMacro`

**Files:** Create `Clocks/macros/reorient_blank_to_xy.FCMacro`; modify `ClockFace-blank.FCStd` in memory.

- [ ] **Step 1: Write the idempotent macro** that:
  1. re-attaches `Sketch` (base profile): `AttachmentSupport=[(XZ_Plane,'')]`, `MapMode` per Task 3.1;
  2. re-attaches `Sketch001` (movement pocket): `AttachmentSupport=[(XY_Plane,'')]`, `MapMode='FlatFace'`/`ObjectXY` per number;
  3. `doc.recompute()` and reports any error objects.

- [ ] **Step 2: Run it; recompute; assert orientation**

Run (MCP). Then check:
```python
bb=App.getDocument("ClockFace_blank").getObject("Body").Shape.BoundBox
_result_={"dx":round(bb.XLength,2),"dy":round(bb.YLength,2),"dz":round(bb.ZLength,2),
          "zmin":round(bb.ZMin,2),"zmax":round(bb.ZMax,2),
          "errs":[o.Name for o in App.getDocument("ClockFace_blank").Objects if o.State and 'Error' in str(o.State)]}
```
Expected: `dz≈3` (thickness now along Z), disc spans X & Y (`dx≈dy≈120`), `errs` empty. If the disc built on −Z, set `Revolution.Reversed`/`Pocket.Reversed` and recompute.

- [ ] **Step 3: Screenshot for review**

MCP `get_screenshot` (Isometric + Top). Present to Bradley. **Do not save until approved.**

- [ ] **Step 4: On approval, save**

Run (MCP): `App.getDocument("ClockFace_blank").save()`.

### Task 3.3: Write & run `reorient_lines_to_xy.FCMacro`

**Files:** Create `Clocks/macros/reorient_lines_to_xy.FCMacro`; modify `ClockFace-lines.FCStd` in memory.

- [ ] **Step 1: Write the macro** — same base+pocket re-attach as blank, then re-attach `Sketch002` (Hours) and `Sketch004` (HalfHour) from `Pocket.Face5` → `XY_Plane` datum (or a `PartDesign::Plane` datum offset to the face surface if the markings must sit on the visible face). Recompute the full tree.

- [ ] **Step 2: Run; recompute; assert orientation + patterns intact**

```python
d=App.getDocument("ClockFace_lines"); bb=d.getObject("Body").Shape.BoundBox
_result_={"dz":round(bb.ZLength,2),"dx":round(bb.XLength,2),"dy":round(bb.YLength,2),
          "pp":[ (o.Name,o.Occurrences) for o in d.Objects if o.TypeId=="PartDesign::PolarPattern"],
          "errs":[o.Name for o in d.Objects if o.State and 'Error' in str(o.State)]}
```
Expected: `dz≈3`, disc in XY, both polar patterns present with `Occurrences=12`, `errs` empty.

- [ ] **Step 3: Marking fallback (recreate) if mis-placed**

If a screenshot shows Hours/HalfHour off the face, not centered, or not radial: recreate that sketch on the datum to reproduce the original geometry (segment count + lengths from Task 2.1 / reorient spec), binding each dimension to its `<<Params>>` Param (Params already exist from Phase 2 — no literals). Re-pad and re-pattern. Recompute.

- [ ] **Step 4: Screenshot (Top + Isometric) for review.** **No save until approved.**

- [ ] **Step 5: On approval, save** `ClockFace-lines.FCStd`.

### Task 3.4: Final audit — no feature-face attachments remain

- [ ] **Step 1: Re-run audit + an explicit feature-face check**

```bash
cd "/Users/bradleycorner/Documents/3dPrinting/Commercial License/Clocks"
python3 scripts/audit_parametric.py 2>&1 | tail -40
```
Plus (MCP) assert no sketch in blank/lines has an `AttachmentSupport` pointing at a `Revolution`/`Pocket`/`Pad` face.
Expected: audit clean of unbound dims AND of feature-face DAG flags for blank/lines.

### Task 3.5: Update WARNINGS.md / CLAUDE.md, commit

- [ ] **Step 1: Update docs** — mark blank & lines as datum-attached + XY-flat (orientation inconsistency resolved); leave XLink wiring as the sole remaining follow-on. Note the two real reorient macros supersede the bootstrap spec's stub.

- [ ] **Step 2: Commit**

```bash
cd "/Users/bradleycorner/Documents/3dPrinting/Commercial License/Clocks"
git add ClockFace-blank.FCStd ClockFace-lines.FCStd macros/ WARNINGS.md CLAUDE.md
git commit -m "Reorient blank & lines to XY-flat; retarget sketches to datums

Matches ClockFace-number structure; removes feature-face DAG debt.
Co-Authored-By: Claude Opus 4.8 (1M context) <noreply@anthropic.com>"
git push
```

- [ ] **Step 3: Final report to Bradley** — orientation done; remaining follow-on = XLink wiring + (deferred) STL/3MF re-export.

---

## Self-Review

**Spec coverage:**
- Bootstrap spec file-ops, git+remote, duplicate deletion, empty Params.FCStd, audit→WARNINGS → Phase 1 + Task 2.5/3.4. ✓
- Reorient spec: re-attach-in-place, datum targets, marking recreate-fallback bound to Params, snapshots, no-save-until-approved, exports deferred → Phase 0.1 + Phase 3. ✓
- Ordering (Params → reorient) → Phases 2 then 3. ✓
- Decoupled clearance Params (MovementShaftClearance, MountingScrewClearance) → Task 2.2. ✓

**Placeholder scan:** The only deliberately data-dependent content is the Params↔constraint MAPPING, which Task 2.1 (inspection) produces and Task 2.2 authors before Task 2.3/2.4 consume it — a real task chain, not a TODO. All file paths, git commands, and verification asserts are concrete.

**Type/name consistency:** macro filenames, doc internal names (`ClockFace_blank`, `ClockFace_lines`, `ClockFace`=number, `ClockBracket`), and Param names are used consistently across tasks. Note `ClockFace-number.FCStd` opens under internal name `ClockFace`; the duplicate `ClockFace.FCStd` shares that internal name — Task 1.7 Step 1 disambiguates by `.FileName` before closing.

**Open risk carried into execution:** whether markings re-attach cleanly vs. need recreate (Task 3.3 Step 3) is only knowable at runtime; both branches are specified.

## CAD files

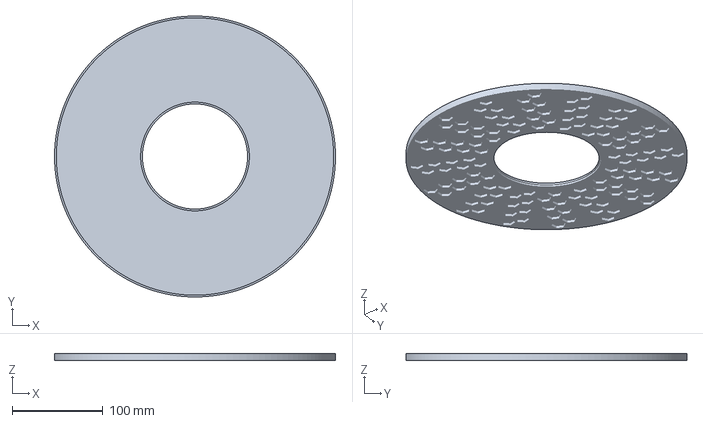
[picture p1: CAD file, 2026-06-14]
3mf/Clock_backing_hex.3mf
310.0 x 309.9 x 7.50 mm

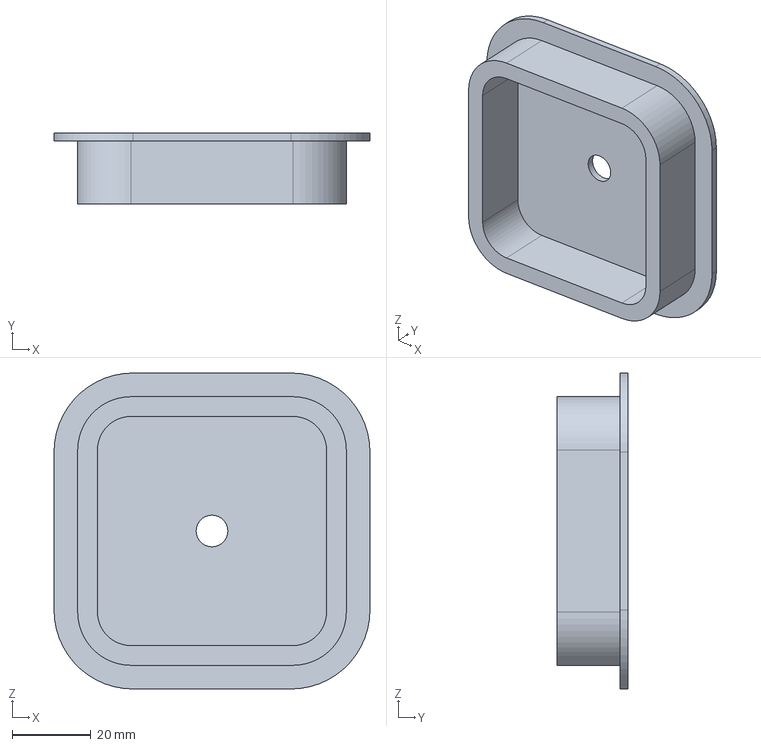
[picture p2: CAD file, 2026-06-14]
ClockBracket.FCStd
80.0 x 18.0 x 80.0 mm

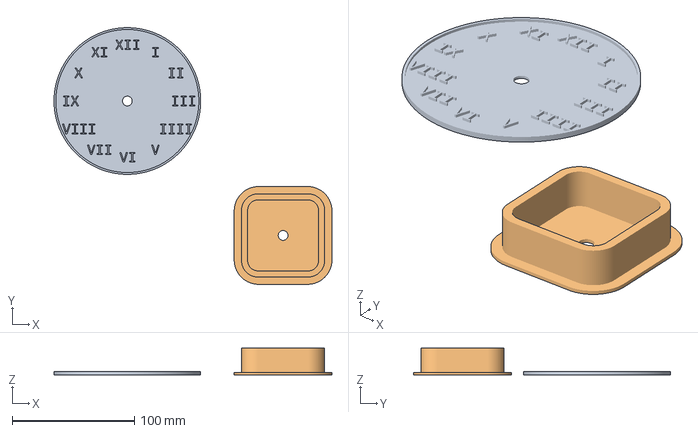
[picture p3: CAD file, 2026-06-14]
Profiles/ClockFace.base.3mf
227.4 x 209.9 x 22.0 mm
ClockFace-roman
ClockBracket.stl

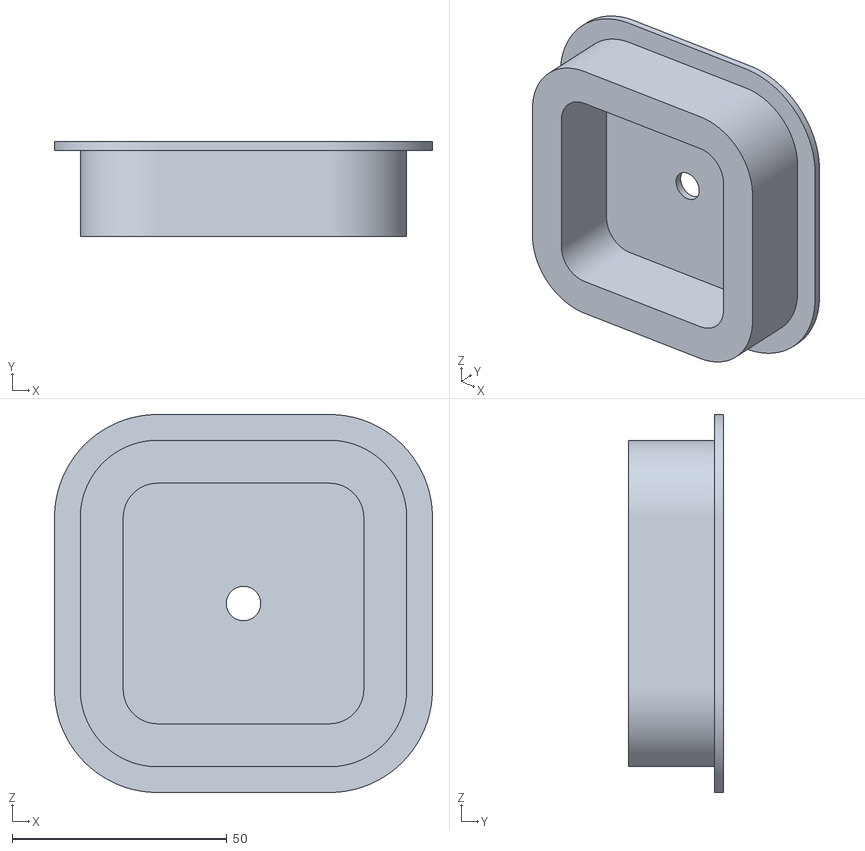
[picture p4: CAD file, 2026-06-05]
stl/ClockBracket-ClockBracket.stl
88.0 x 22.0 x 88.0

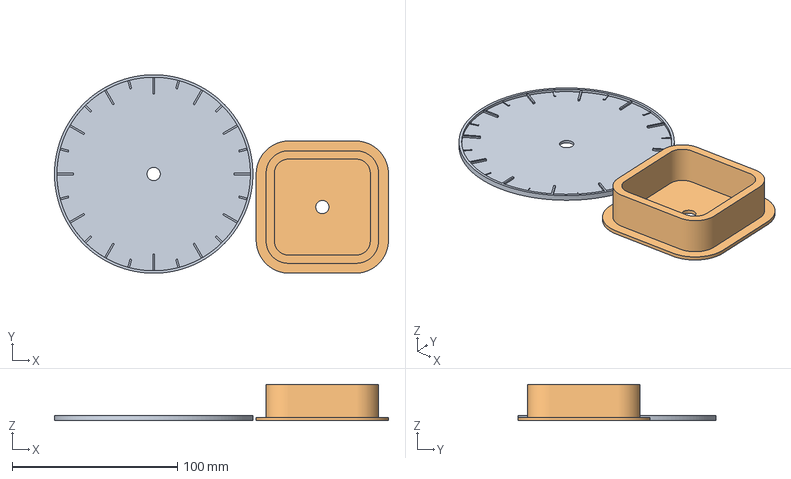
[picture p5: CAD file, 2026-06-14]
3mf/Clock.3mf
202.0 x 120.0 x 22.0 mm
ClockFace-lines-Body.stl
ClockBracket.stl

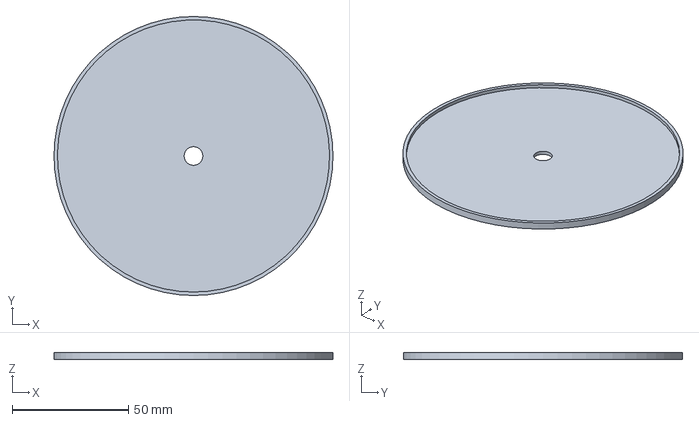
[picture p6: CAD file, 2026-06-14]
ClockFace-NumberStyle_2.FCStd
120.0 x 120.0 x 3.00 mm

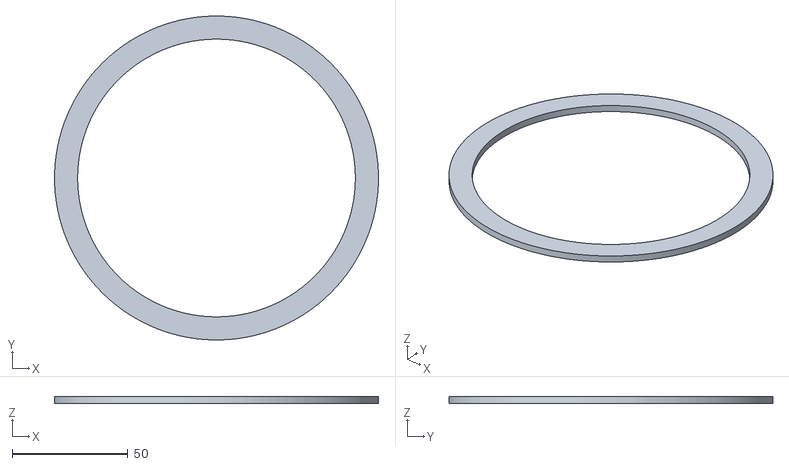
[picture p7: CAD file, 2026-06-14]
Clock_backing--Body.stl
140.0 x 140.0 x 3.00

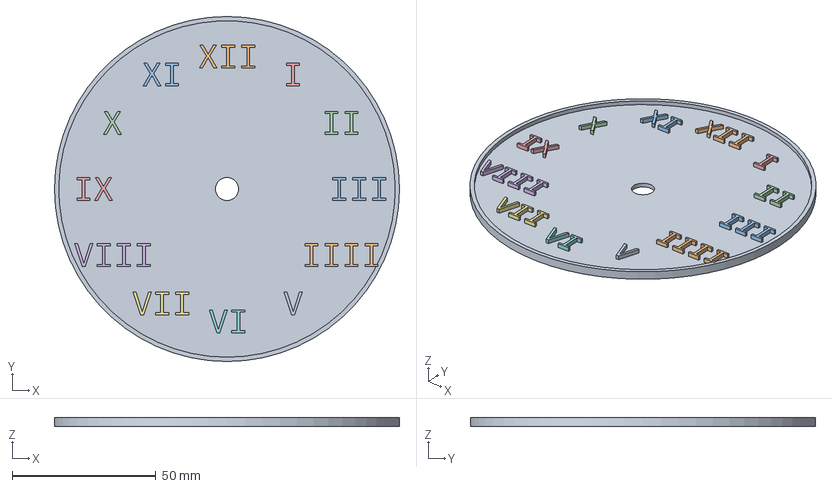
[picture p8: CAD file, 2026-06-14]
ClockFace-roman.FCStd
120.0 x 120.0 x 3.00 mm
XII001
XI001
X001
IX001
VIII001
VII001
VI001
V001
IIII001
III001
II001
I001
Comp_Roman

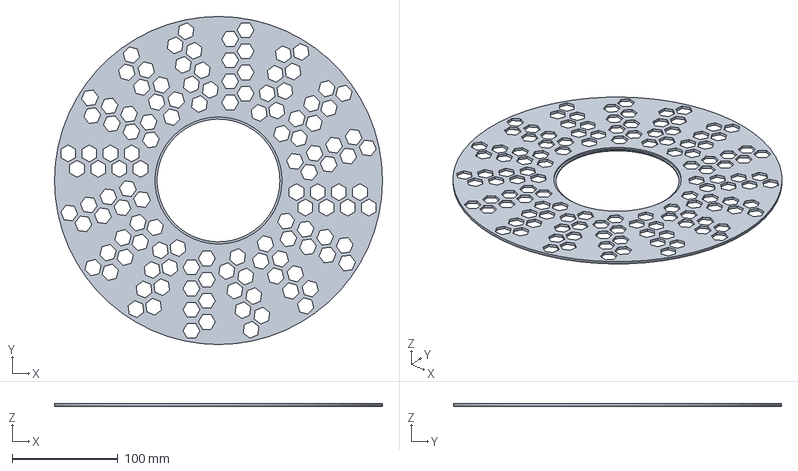
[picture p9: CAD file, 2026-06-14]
Clock_backing.FCStd
310.0 x 310.0 x 2.50 mm

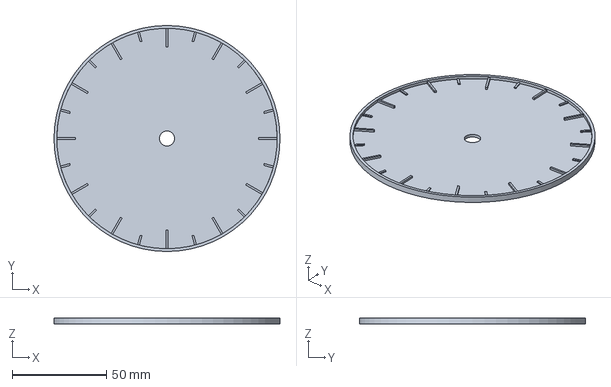
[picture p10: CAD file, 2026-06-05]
ClockFace-lines.FCStd
120.0 x 120.0 x 3.00 mm

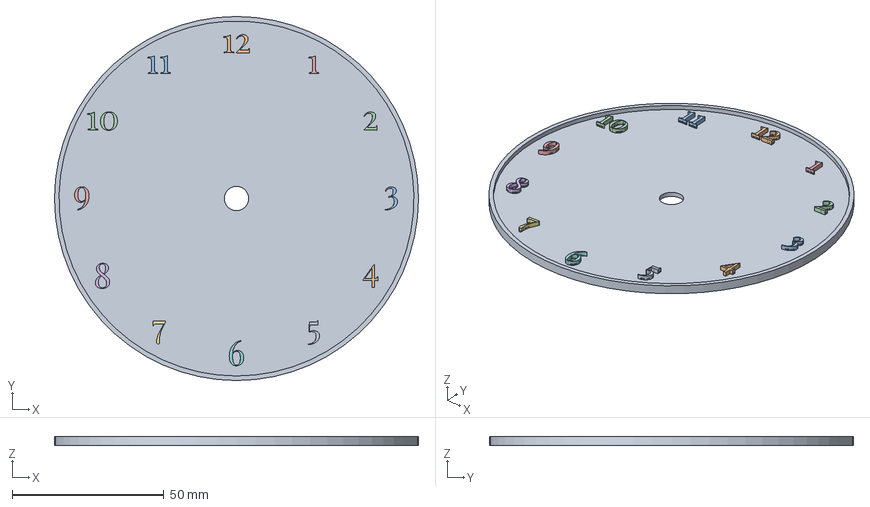
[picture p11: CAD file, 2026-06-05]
ClockFace-number.FCStd
120.0 x 120.0 x 3.00 mm
Comp_Arabic001

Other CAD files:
ClockAssembly.FCStd
ClockFace-blank.FCStd
Params.FCStd
3mf/ClockBracket.3mf
3mf/ClockFace-NumberStyle_2.3mf
3mf/ClockFace-blank.3mf
3mf/ClockFace-lines.3mf
3mf/ClockFace-number.3mf
3mf/ClockFace-roman.3mf
3mf/Clock_backing.3mf
ClockBracket.3mf
ClockBracket.stl
Clock_backing.3mf
stl/ClockBracket.stl
stl/ClockFace-blank.stl
stl/ClockFace-lines.stl
stl/ClockFace-number.stl

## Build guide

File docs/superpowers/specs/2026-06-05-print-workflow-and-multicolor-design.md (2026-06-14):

# Print Workflow & Multi-Color — Design Notes

**Date:** 2026-06-05
**Project:** Clocks (several items are workspace-wide candidates — flagged inline)
**Status:** Ideas captured from working session — NOT yet an approved implementation spec
**Type:** Workflow design + modeling direction + bug findings

---

## Why this doc

Capturing the print-pipeline thinking from the 2026-06-05 session so it isn't trapped in
chat (or in unsaved slicer state). Covers: the deliverable model, print-profile reuse,
multi-color strategy, where the 2cv001 macro fits, and two real defects found in the existing
3MFs. Nothing here is built yet; open decisions are listed at the end.

---

## 1. Deliverable model (per printable body)

- **STL** — pure geometry. For publishing (Creality Cloud etc.) and as the import seed.
  FreeCAD owns it; we already export at 0.01 mm deflection (watertight/manifold).
- **Profile 3MF(s)** — a 3MF only carries a print profile if it is a **slicer *project*** 3MF
  (settings live in `Metadata/project_settings.config`). FreeCAD cannot bake a profile in — it
  only writes meshes. So each profile-3MF is produced/owned in **Creality Print**, seeded from
  the STL.
- Shape of it: **per body → 1 STL + N profile-3MFs** (one per target plate). The 3MF doubles
  as a publish artifact (modern format, carries color).

**Suggested layout** (scales to N profiles without name collisions):
```
stl/  ClockFace-lines.stl                 ← geometry / publish
3mf/holoplate/  ClockFace-lines.3mf       ← Creality project, Holo profile
3mf/standard/   ClockFace-lines.3mf       ← Creality project, standard plate
```
**Workspace-wide candidate:** promote this deliverable convention into `PROJECT_BOOTSTRAP.md`.

---

## 2. Print profiles (reuse)

- A tuned profile is fully reusable across **all** projects and **any** object count
  (single part or assembly) — it's geometry-independent.
- **The holo-plate profile is high-value IP** (days of tuning) and currently lives only inside
  one Creality Print install. Two actions:
  1. Save it as a **named Process preset** → appears in every project's process dropdown.
  2. **Export it to a file** (Creality Print preset export / config bundle) and store it in a
     version-controlled home so it survives reinstalls/machines.
- **Proposed home (workspace-wide):** `Commercial License/Profiles/` with
  `Holo-K2Plus.json` etc. + a `README.md` documenting export/import + naming.
- Holo behavior is encoded in the Process settings (first layer, bottom-surface pattern, plate
  temp, flow) on the chosen bed type — confirm whether Creality Print exposes a dedicated
  "holographic" bed type or it's tuned on Textured-PEI. (Open Q1.)

---

## 3. Multi-color strategy — the core idea

**Problem:** the proven black-face / red-tick clock was colored with **paint-by-layer** in the
slicer. That is a per-project **manual step that does not survive a geometry re-export** —
re-import an updated STL and the paint is gone. Goal: eliminate that step.

**Target approach — color = geometry, assigned per object:**
- Make each color region its **own object** so the slicer assigns filament **per object**
  automatically. Per-object assignment is the most portable form — survives re-export, is what
  a base/template 3MF remembers, needs zero painting. Open the plate → confirm CFS slot per
  object → slice.
- For the line face that means exporting **two objects**:
  - **body** (disc + dial) → base-color slot
  - **accents** (tick marks; rim too if desired) → accent-color slot
  - plus **bracket** → its slot
- This single direction solves three things at once:
  1. kills paint-by-layer (color is geometry, not a slicer action),
  2. *is* the multi-color assembly plate,
  3. is exactly the multi-body export the stock macro can't do (§4).

**Cost / requirements — and the two SKUs sit at opposite ends:**
- **`number` is already structured right.** Its 12 numerals are **separate `Part::Extrusion`
  objects**, not fused into the Body. That's exactly the per-object color structure we want:
  include them in the export and assign disc→base / numerals→accent. (The only reason
  `ClockFace-number.3mf` looked broken is a Body-only export dropped them — §5b.)
- **`lines` is the one needing surgery.** Its tick markings are **PartDesign Pads/PolarPatterns
  fused into the single Body** — that's *why* it exported cleanly as one solid, but it means a
  second color requires **un-fusing / splitting the tick volumes back out** into their own
  object (e.g. a separate body, or isolate the pad volumes). Real work, more than number.
- **The bezel rim** (on both face SKUs) is part of the disc revolve; making *it* a separate
  color would need its own split. (Open Q2 decides whether we go there.)
- **Export — VERIFIED 2026-06-05 on `ClockFace-number`:**
  - The **GUI File→Export** path rejects loose Part objects / groups ("no body selected") — this
    is a GUI-command guard, *not* a FreeCAD limit.
  - **Scripting `Mesh.export()` exports anything with a shape** — tested OK on the Body, a single
    numeral `Part::Extrusion`, the `FcClock001` group, and Body+all-numerals.
  - **It keeps objects SEPARATE in 3MF (does not merge):** `Mesh.export([Body]+12 numerals,
    .3mf)` → a 3MF with **13 objects / 13 meshes / 13 build-items**. (STL, by contrast, merges
    everything into one mesh.) So a **multi-object 3MF straight from FreeCAD scripting is the
    mechanism** — fuse the 12 numerals into one accent object → export `[disc, numerals]` → clean
    2-object 3MF.
  - The **only** thing FreeCAD won't write is Creality's per-object **slot** metadata
    (`model_settings.config` `<metadata key="extruder">`). So slot mapping is set once in a
    **Creality Print template**, or **stamped by a small post-export script**. (This is the piece
    worth automating — and the capability the single-body macro lacks.)

**VALIDATED end-to-end (2026-06-05, Creality Print).** The FreeCAD-generated multi-object 3MF
(`~/Downloads/ClockFace-number-PROOF.3mf`) opened in Creality Print as **13 separate objects**;
disc → slot 1 (orange), numerals → slot 3 (red) assigned per object; renders correctly with the
numerals **~1–2 mm proud** (raised relief, *not* engraved — earlier guess corrected). So
FreeCAD → multi-object 3MF → per-object color is **proven**.

**New requirement found in the same test — objects must be ASSEMBLED.** The 13 objects are
independent, so moving the disc leaves the numerals behind, and overlapping objects raise a
"too close / collisions" warning. Fix has two parts:
1. **Fuse the 12 numerals into one accent object** → clean **2-object** plate (disc + numerals).
2. **Mark as an assembly** so they move as one unit — in a Creality/Bambu 3MF this is the
   `<assemble><assemble_item …>` block in `model_settings.config` (present in `Clock.3mf`).
   FreeCAD won't write it → either a one-time "Assemble" in Creality Print, or the export-stamp
   script writes it.

**FULLY VALIDATED (2026-06-05) — the clean 2-object `3mf/ClockFace-number.3mf`.** Opened in
Creality Print → it prompts **"Multi-part object detected … load as a single object with
multiple parts?"** → **Yes**. Result: one object `ClockFace-number` with two **parts**
(`Object_1` disc, `Object_2` text), each assigned its own filament slot, **moving together as a
unit**, numerals proud and crisp on the dial. So the full chain works:
`build → FCCircularText → seat_circular_text_proud → export_face_multicolor_3mf →
Creality Print "multi-part: Yes" → assign 2 slots → slice` — no painting, no manual assemble.

**Key consequence — the `<assemble>` block is NOT needed.** Creality Print's multi-part import
does the grouping *and* per-part coloring on load. So:
- **Workflow as-is** needs zero stamping; the only manual step is assigning the 2 slots after import.
- **Optional stamp script** would only **pre-assign the 2 slots** (`model_settings.config`
  `<metadata key="extruder">` per object) to remove that one step — it does **not** need to write
  `<assemble>`. (Earlier "stamp must write `<assemble>`" is superseded.)

The reusable export tool is `macros/export_face_multicolor_3mf.FCMacro`; the seat-proud tool is
`macros/seat_circular_text_proud.FCMacro`.

**Open Q2:** accent = **ticks only**, or **ticks + rim**? (Decides whether we touch the bezel.)
**Open Q3:** confirm the target mental model is "color = separate objects, one slot each, no
painting ever." (Working assumption: yes.)

---

## 4. The 2cv001 "3D Printer 3mf Workflow" macro — role & limits

Macro: `~/Library/Application Support/FreeCAD/v1-1/Macro/3D_Printer_3mf_Workflow.FCMacro`
(Apache-2.0). It injects FreeCAD's fresh mesh into a **base 3MF that already carries slicer
settings**, preserving all settings files → outputs a project 3MF with the profile **baked in**,
and can launch the slicer.

- **This is how FreeCAD can emit a profile-bearing 3MF** (via the "3MF file for print
  parameters" field = a profile template). Exactly the §1/§2 deliverable for single parts.
- **"Old version / only the object" issue = the fallback path**, not a bug: with no compatible
  base 3MF it writes a bare, namespace-less core 3MF (`build_model_xml`, ~line 945) that Orca/
  Creality imports as a plain object. **Fix = feed it a Creality-Print-made base 3MF** (and set
  `slicer_exe` to Creality Print; default is QIDI Studio). Mismatched base-vs-target slicer
  triggers an "incompatible slicer" fallback to the same bare file (~line 2387).
- **Hard limit — single body** (line 1911 `if len(selection) > 1: … "Multiple selection not
  supported."`). So the macro is good for **single-part profile 3MFs only**. It **cannot** build
  the multi-color / multi-part plate. Assemblies → Creality Print, or a macro modification.

**Decision (working):** use the macro for single-part profile 3MFs; do **not** rely on it for
multi-color assemblies. If we automate multi-object color export, build it ourselves (§3) rather
than fight the macro's single-body design.

---

## 5. Defects found in existing 3MFs (2026-06-05)

### 5a. `Clock.3mf` does not contain the recipe that printed the photo
The committed `3mf/Clock.3mf` is an **early save**: both objects on slot 4 (black), **no paint
data**, `custom_gcode_per_layer.xml` has the `MultiExtruder` flag but **zero actual color
changes**, mesh has no segmentation. It also still holds the **old vertical** line-face geometry.
The good two-color result lives only in an **unsaved Creality Print session**. Action: re-save/
export the good project from Creality Print over the stale file before reusing it as a template.

### 5b. `ClockFace-number.3mf` is missing the numerals — they're not in the Body
- The numerals **are correct, visible geometry** on the dial face (confirmed in the FreeCAD
  view). Earlier "buried" call was **wrong** — corrected here.
- They are **12 separate `Part::Extrusion` objects** (group `FcClock001` + `Comp_Arabic001`/
  `Shape001`), **not part of the PartDesign `Body`**. The committed `ClockFace-number.3mf` is a
  **Body-only export** (single bare object, ~1440 verts), so it omits them → "numbers missing."
- Number's center **bore is now consumed** (`Body` tip = `Pocket`, UpToFirst, Reversed) — so the
  earlier "unconsumed bore" note is outdated.
- **Fix:**
  - *Single-color:* export `Body` **+ the numeral objects** together (not Body-only) and the
    numbers come through.
  - *Multi-color (preferred):* the numerals being a **separate object** is exactly what §3 wants
    — assign disc→base slot, numerals→accent slot. So **number is already well-structured for
    multi-color**, it just needs the export to (a) include the numerals and (b) ideally collapse
    the 12 extrusions into one "numerals" object with the accent slot baked in.
- So this is **not** a quick "the SKU is broken" — the geometry is fine; it's the same
  per-object multi-color export need as the line face (§3).

---

## 6. Open decisions

- **Q1** — Holo: dedicated bed type in Creality Print, or tuned on Textured-PEI? (doc detail)
- **Q2** — Accent color = ticks only, or ticks + rim? (bezel split or not)
- **Q3** — Confirm target model: "color = separate objects, one slot each, no painting."
- **Q4** — Promote the deliverable layout (§1) + `Profiles/` home (§2) to `PROJECT_BOOTSTRAP.md`
  (workspace-wide), or keep Clocks-local for now?
- **Q5** — Number SKU: redesign now (numerals as color object + consume bore), or defer?
- **Q6** — Multi-object color export: one-time Creality Print template vs. a post-export
  slot-stamping script (or a forked multi-body macro)?

## 7. Sequencing (proposed, once decisions land)

1. Rescue assets: re-save good `Clock.3mf` from Creality Print; export + back up the Holo
   profile into `Profiles/`.
2. Confirm the color split (Q2/Q3) and the deliverable/standards scope (Q4).
3. Modeling: **number** is mostly there (numerals already separate, bore already consumed) —
   just collapse the 12 numeral extrusions into one accent object and include it in the export.
   **lines** needs the real work — un-fuse the tick volumes from the Body into a separate accent
   object.
4. Export automation: decide Q6, implement multi-object 3MF with per-object slots.
5. Document the per-project workflow; regenerate the clean deliverables.

---

## 8. PAUSED (2026-06-06) — baking print settings into the export

Status as of pause: number + roman faces print well via the 3-object (base/bezel/text) export +
Creality "multi-part: Yes" + manual 3-slot assignment. The remaining want: the exported `.3mf`
should carry the **print settings** (global `project_settings.config` + object/part
`model_settings.config`) so it opens ready — same idea as the 2cv001 macro's "reference a base 3MF".

How 2cv001 does it: a `.3mf` is a zip; it opens the referenced base, overwrites **only** the
geometry `.model`, copies every other file (settings) through, rewrites the zip. Simple — but it
swaps a **single** mesh (single-body macro).

The open decision — which base, which approach:

- **Option A (recommended): save a 3-PART base.** In Creality, save the working Roman/number plate
  (3 parts already assigned to slots) as `Profiles/ClockFace.base.3mf`. It then has the settings
  AND the exact 3-part/slot/assemble structure. The injector becomes the literal 2cv001 trick,
  just **3 meshes swapped in** (matched by order: base, bezel, text). Low risk, no format guessing.
- **Option B: use `Clock.3mf` as base.** It carries the settings but is a **2-object** plate
  (lines + bracket, `<assemble>` of separate objects). Reusing it means hand-rebuilding Creality's
  full 3-part project format (root `3dmodel.model` → external `3D/Objects/object_N.model` →
  `model_settings.config` parts/extruders/assemble, rels, UUIDs, Content_Types). Deterministic but
  fragile; needs several open-test-fix cycles in Creality.

Creality 3MF structure (verified from Clock.3mf, for whoever builds this): root `3D/3dmodel.model`
holds `<object>`s whose `<components>` reference external `/3D/Objects/object_N.model` mesh files;
`<build><item>` places each with a transform; `Metadata/model_settings.config` defines objects/
parts + `<metadata key="extruder">` (slot) + `<assemble>`; `Metadata/project_settings.config` is
the global profile (this plate: 0.12 layer, 2 walls, 15% infill, Textured PEI). Namespaces:
microsoft 3dmanufacturing core + BambuStudio + production `p`.

Slot assignment is per-colorway (user choice) — the injector should take 3 slot numbers (config),
defaulting to something sane, leaving final tweak to the slicer.

**Next action when resumed:** pick Option A or B. If A, user saves `ClockFace.base.3mf`; then build
the 3-mesh swap injector (extend `export_face_multicolor_3mf` with a BASE_3MF option).

---

## 9. PAUSED again (2026-06-14) — settings injection, decision still open

Base was saved (`Profiles/ClockFace.base.3mf`). Inspecting it changed the plan:

- The saved base is a **full Creality project**: one face-object with **3 parts** (dial/bezel/text)
  **plus the bracket**. Creality **re-centers each part to its own bbox center** and bakes per-part
  transforms — the **text part carries a geometry-specific X offset**. So a naive "swap the meshes"
  (2cv001-style) does NOT reposition a *different* face's text correctly; the transforms are tied to
  the Roman geometry.
- Note: Creality's save **overwrote** the bare world-coord `3mf/ClockFace-roman.3mf` with the project
  (both it and the base are now the same 96 KB project file).

**Three paths (UNDECIDED — user to choose on resume):**
- **A — Process preset (simplest, recommended).** Save the tuned settings once in Creality as a
  named **Process preset** (not a project). Select it for any face. No injection, no file work; only
  the 3-slot pick stays manual. Gets ~90% of the value for ~30s setup.
- **B — Stamp only the profile.** Bake `project_settings.config` onto a world-coord export; opens
  profile-loaded, still needs "multi-part: Yes" + 3 slots. No transform math.
- **C — Full injection (turnkey file).** Transform-aware injector recomputes each part's placement
  for new meshes → opens fully loaded + pre-colored. Most convenient, but multi-iteration build with
  format risk; needs Creality load-tests (can't self-verify).

**Resume here:** pick A / B / C. (If C, the injector must recompute per-part transforms, not just
swap meshes — that's the crux.)

## State at pause (2026-06-14)
New, uncommitted-until-this-save work present: `ClockFace-roman`, `ClockFace-NumberStyle_2`,
`Clock_backing`, `ClockAssembly` FCStds + their 3MFs; `Profiles/ClockFace.base.3mf`; an exported
Creality printer profile zip. Origin-stub STLs (`*--*-axis.stl`, `*--*-plane.stl`) are gitignored.

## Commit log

2026-06-05 Retroactive bootstrap: scaffold Clocks project per PROJECT_BOOTSTRAP.md
    Adds CLAUDE.md, intent/plan/README/WARNINGS, standards copies, audit script,
    empty Params.FCStd, and directory layout around existing in-progress FCStds.
    Relocates ClockFace-number exports into 3mf/ and stl/. Geometry untouched.
    [Clock.3mf, ClockBracket-ClockBracket.stl, ClockBracket.3mf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]
2026-06-05 Params migration: central VarSet (21 params) + bind all literal constraints
    - Populate Params.FCStd VarSet from current literal values (faithful, no redesign)
    - Bind 36 sketch/feature dims across bracket/blank/lines/number to <<Params>>#VarSet.*
    - Migrate bracket's pre-existing local VarSet (InsideDistance -> BracketInnerInset), delete it
    - Geometry verified bit-identical (bbox+volume); FaceDiameter round-trip proves live drive
    - Fix Clocks copy of audit_parametric.py: correct Sketcher constraint-type enum (was
    mislabeling Tangent/Perpendicular/Block as dimensions), Type-aware feature dims, 90deg-angle
    exemption. Corrected audit: only the 4 expected feature-face DAG flags remain (Phase 3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
    [ClockBracket.FCStd, ClockFace-blank.FCStd, ClockFace-lines.FCStd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]
2026-06-05 Reorient blank & lines to XY-flat (ridge up); retarget sketches to datums
    - blank/lines base Sketch -> XZ_Plane (ObjectYZ, MapReversed), Sketch001 -> XY_Plane;
    Pocket.Reversed for the ridge-up flip. Disc now Z 0->3, matching ClockFace-number.
    - lines Hours/HalfHour markings moved off Pocket.Face5 onto a DialFaceDatum plane whose
    Z binds to FacePlateThickness. Pattern bbox + body volume unchanged (no recreate needed).
    - Removes the last feature-face DAG attachments: full project now passes audit_parametric.py.
    [ClockFace-blank.FCStd, ClockFace-lines.FCStd]
2026-06-05 Re-export blank & lines STL/3MF in XY-flat orientation
    Regenerated at 0.01mm linear deflection (smooth Ø120 rim): blank 2192 tris, lines 2766 tris.
    Both verified watertight/manifold, no self-intersections. Removes the stale
    ClockFace-lines-Body.stl (old vertical orientation).
    [ClockFace-blank.3mf, ClockFace-blank.stl, ClockFace-lines-Body.stl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]
2026-06-05 Design notes: print workflow, profiles, multi-color, macro role, 3MF defects
    Captures the 2026-06-05 session: STL+profile-3MF deliverable model; holo-profile reuse/backup;
    multi-color via per-object geometry (kills paint-by-layer); the 2cv001 macro's role and
    single-body limit; and two findings — Clock.3mf lacks the printed recipe, and ClockFace-number
    numerals are separate embedded Part extrusions (number SKU only works as a multi-color part).
2026-06-05 Correct number/lines structure in design notes
    - Numerals are visible on the face (not buried); they're separate Part::Extrusion objects, so a
    Body-only export drops them. number's center bore IS consumed (Pocket) - earlier note was stale.
    - Key contrast: lines markings are FUSED into the Body (one solid -> exports clean, but needs
    un-fusing for a 2nd color); number numerals are already separate objects -> already
    multi-color-ready. number is the better-structured SKU; lines is the one needing surgery.
2026-06-05 Verify multi-object 3MF export from FreeCAD scripting
    Tested on ClockFace-number: GUI export rejects loose Part objects/groups ('no body selected'),
    but scripting Mesh.export handles Body, single extrusions, the group, and Body+numerals - and
    keeps objects SEPARATE in 3MF (Body+12 numerals -> 13-object 3MF; STL would merge). So a
    multi-object 3MF straight from FreeCAD is the mechanism; only the per-object CFS slot metadata
    needs a template or a stamp script.
2026-06-05 Multi-color validated in Creality Print + assembly requirement
    Proof 3MF opened as 13 objects; disc->slot1, numerals->slot3, renders correct, numerals ~1-2mm
    proud (raised, not engraved). FreeCAD->multi-object 3MF->per-object color is proven. New
    requirement: objects must be assembled (model_settings <assemble> block) so disc+numerals move
    together; fuse 12 numerals to 1 -> clean 2-object plate. Stamp-script spec now crisp: fuse,
    export 2 objects, stamp slots + <assemble>.
2026-06-05 ClockFace-number: seat numerals proud of dial; add generic seat-text tool
    - Numerals were Part::Extrusions at Z 0->2 (through the dial plate to the back, ~0.5mm proud).
    Reseated to Z dial(1.5)->3.0 = proud of the dial, nothing below it; height bound to new Param
    NumeralReliefHeight (1.5). Removes the 'numbers go clear through the disk' issue.
    - Add macros/seat_circular_text_proud.FCMacro: generalized, runs on the active doc, seats any
    FCCircularText Part::Extrusion glyphs on the dial proud, Params-bound, snapshot-first. Reusable
    for future faces (build face -> FCCircularText -> run this -> export as 2-object 3MF).
    - Audit still clean across all 5 files.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
    [ClockFace-number.FCStd, Params.FCStd]
2026-06-05 Tidy: archive stray root exports; gitignore archive/; absorb benign FCStd re-saves
    - Moved untracked root-level ClockFace-lines.3mf/.stl (workflow-macro scratch output) into
    archive/ (gitignored holding pen).
    - ClockBracket/blank/lines FCStds had binary re-save churn (GUI/view-state only; geometry
    verified unchanged - audit clean) - committed to clean the working tree.
    [ClockBracket.FCStd, ClockFace-blank.FCStd, ClockFace-lines.FCStd]
2026-06-05 ClockFace-number: regenerate as clean 2-object multi-color 3MF
    Replaces the broken Body-only export. Disc (2192 facets) + the 12 proud numerals fused into one
    'text' object (16032 facets) = 2 separate objects in the 3MF, world-positioned (numbers stay on
    the dial). Ready for per-object filament assignment + Assemble in Creality Print.
    Adds macros/export_face_multicolor_3mf.FCMacro: reusable export tool (run on active face ->
    Body + combined text glyphs -> 2-object 3MF in 3mf/<DocLabel>.3mf). FreeCAD can't write slot/
    <assemble> metadata; that's the stamp-script follow-on.
    [ClockFace-number.3mf]
2026-06-05 ClockFace-number: regenerate STL with numerals (boolean-fused, watertight)
    Replaces the broken Body-only STL. Disc + 12 proud numerals fused into one watertight/manifold
    solid (18260 facets) for single-color publishing. (Multi-color stays the 2-object 3MF.)
    [ClockFace-number.stl]
2026-06-05 Multi-color pipeline FULLY validated in Creality Print
    2-object 3mf/ClockFace-number.3mf opened, chose 'multi-part object: Yes' -> one object with two
    parts (disc + text), per-part filament, moving together, numbers proud/crisp. Full chain proven:
    build -> FCCircularText -> seat_circular_text_proud -> export_face_multicolor_3mf -> Creality
    'multi-part: Yes' -> assign 2 slots -> slice. Consequence: <assemble> block not needed (Creality's
    multi-part import groups + colors on load); optional stamp script would only pre-assign slots.
2026-06-05 Add dial/bezel split to export macro; regenerate number as 3-object 3MF
    export_face_multicolor_3mf now splits the disc at radius (FaceDiameter/2 - BezelWidth) into
    inner dial + outer bezel ring, so the bezel is its own colour object - no hand-painting. Verified
    clean: dial 16051.6 + bezel 1675.3 = disc 17726.9. 3mf/ClockFace-number.3mf is now 3 objects
    (dial + bezel + text). SPLIT_BEZEL flag toggles 2- vs 3-object output.
    [ClockFace-number.3mf]
2026-06-05 Add FACE_WORKFLOW.md: repeatable recipe for new face variants
    Save-As template -> swap numbers via FCCircularText -> seat_circular_text_proud ->
    export_face_multicolor_3mf (3-object dial/bezel/text) -> Creality 'multi-part: Yes' + 3 slots.
2026-06-05 Fix bezel split: proud lip only (outer ring above dial face), not full-height ring
    Bezel object was the full-height outer ring; corrected to the outer ring ABOVE the dial face
    (r > FaceDiameter/2-BezelWidth AND Z > FacePlateThickness) = just the raised rim lip. Base keeps
    the flat plate + dial. Verified: base 16889.2 + bezel 837.6 = disc 17726.8; bezel vol matches
    the exact lip ring. 3 objects in file (base/bezel/text 16032 tris) - numbers intact.
    [ClockFace-number.3mf]
2026-06-05 Harden export macro to run on any virgin face, not just this number file
    - Center the bezel cut on the disc's actual BoundBox XY center (was assuming origin).
    - Skip the bezel split when a face has no proud rim lip above the dial face (export disc whole).
    - Make text optional (a face may have no FCCircularText glyphs yet).
    - Radius + dial-face Z stay Params-driven with fallbacks.
    Regression: number still exports base/bezel/text identically.
    [ClockFace-number.3mf]
2026-06-06 Capture paused decision: baking print settings into the export (base-3MF options A/B)
2026-06-14 Add Profiles/ home for the canonical ClockFace.base.3mf (settings injection, Option A)
    Documents the single-base approach: one ClockFace.base.3mf carries the print profile + 3-part
    structure + slots/assemble; the export injector swaps each face's 3 meshes into a copy. Injector
    built/verified against the real base once it's saved here.
2026-06-14 Save session state before reboot — multiple faces + base; settings-injection undecided
    New work preserved: ClockFace-roman, ClockFace-NumberStyle_2, Clock_backing, ClockAssembly
    (FCStds + 3MFs); Profiles/ClockFace.base.3mf (the saved Creality base); exported Creality printer
    profile zip. Design doc §9 records the open A/B/C settings-injection decision and the key finding
    (Creality re-centers each part with baked transforms, so full injection must recompute per-part
    placement). Origin-stub STLs gitignored. Some stray root-level exports captured as-is; organize later.
    [Clock.3mf, ClockAssembly.FCStd, ClockBracket.3mf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]
